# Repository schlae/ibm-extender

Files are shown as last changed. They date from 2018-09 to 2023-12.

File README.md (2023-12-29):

# IBM 5161 Expansion Chassis Cards

This project duplicates both the extender and receiver cards used in the IBM
5161 expansion chassis. This is a box that looks identical to an IBM PC, only
it has simple backplane instead of a motherboard. An extender card located in
a host PC/XT system connects to a receiver card located in the expansion
chassis using a large 62-pin D-sub cable.

Even if you don't own (all or part) of an IBM 5161, this project may still be
useful to you. It works perfectly with various passive ISA backplanes! There
is one slight catch--the 14.318MHz ISA bus clock signal is generated on the
IBM backplane but not typically on passive ISA backplanes. Not all cards need
this signal, however. Often you can check by tracing the edge connector contact
B30 on the back of an ISA card. It is second-furthest from the bracket. If the
contact is missing or not connected to a trace, the card should work.

Further information on the IBM 5161 is available from [minuszerodegrees.net](http://minuszerodegrees.net/5161/doco/5161_documentation.htm).

Someone else has reverse engineered and cloned the 5161 backplane. See [here](https://gitlab.com/trs-eric/5161-planar-backplane-board).

Incidentally, the 62-pin cable is available from Mouser Electronics,
923-PCL-10162-1E. Use the 1 meter cable; anything longer may cause signal
integrity issues.

The card bracket, Mouser Electronics 534-9200-5, has been reported to fit.
I have not personally tried it.

The IBM PC and XT BIOS run some tests on the card on boot. If you see an
"1801" code on boot, it may mean something as simple as an unconnected cable
or an unpowered expansion chassis. It'll pop up for any other error with the
card. For troubleshooting, you may have more luck writing test programs in
BASIC using the inp() and out() functions. Test registers are documented
in the [IBM technical reference manual](http://minuszerodegrees.net/oa/OA%20-%20IBM%20Expansion%20Unit%20(5161).pdf).

On to the cards themselves! These are both 4-layer boards. I got mine with
immersion gold edge fingers and a 30 degree edge bevel, but both these are
optional. The ideal is to use selective hard gold for the edge fingers,
but this tends to be quite expensive.

## Extender Card
Here is what the extender card looks like. Components shown may vary from the
official bill of materials.
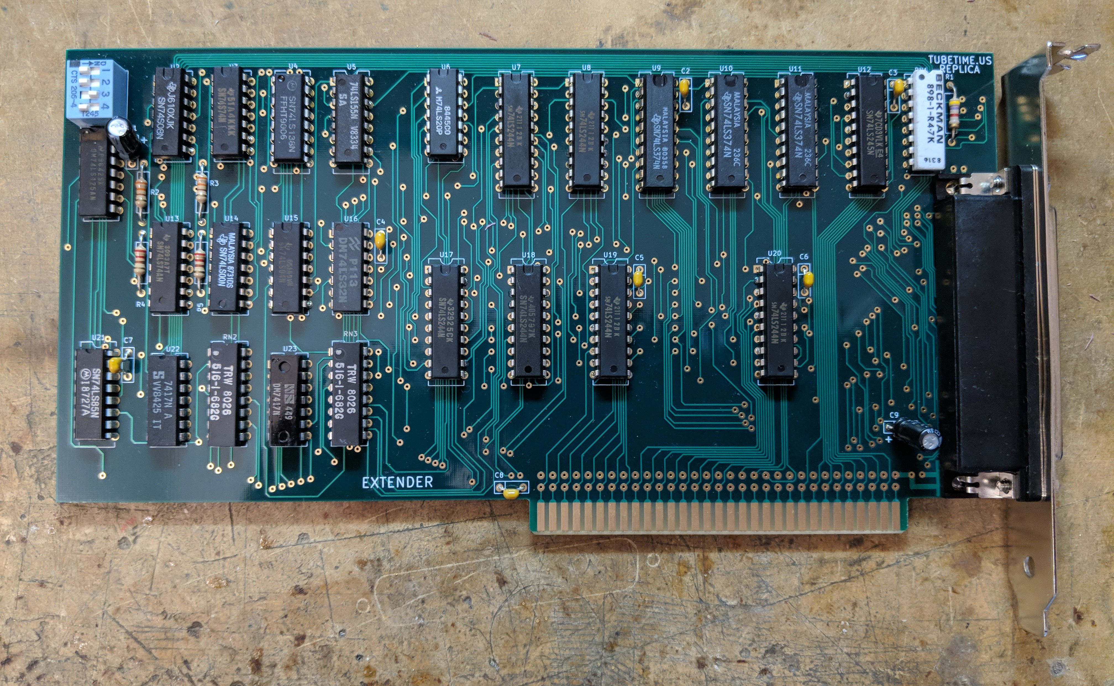
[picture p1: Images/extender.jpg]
Extender card photo


There is a switch bank in the upper left corner. This configures the wait-state
generator which is necessary if you need to access RAM or ROM on any other card
in the expansion chassis. Placing RAM expansion cards in the chassis is not
recommended since it slows everything down. The wait-state generator starts at
0xEFFFF and extends downwards to the configured address. ROM at 0xF0000-0xFFFFF
is reserved for system BIOS and never gets an additional wait state.

1=On, 0=Off/Open

| Switches  1234 | Address Range with Wait State |
|:---:|---|
| 1111 | 0x00000-0xEFFFF |
| 1110 | 0x10000-0xEFFFF |
| 1101 | 0x20000-0xEFFFF |
| 1100 | 0x30000-0xEFFFF |
| 1011 | 0x40000-0xEFFFF |
| 1010 | 0x50000-0xEFFFF |
| 1001 | 0x60000-0xEFFFF |
| 1000 | 0x70000-0xEFFFF |
| 0111 | 0x80000-0xEFFFF |
| 0110 | 0x90000-0xEFFFF |
| 0101 | 0xA0000-0xEFFFF |
| 0100 | 0xB0000-0xEFFFF |
| 0011 | 0xC0000-0xEFFFF |
| 0010 | 0xD0000-0xEFFFF |
| 0001 | 0xE0000-0xEFFFF |
| 0000 | Wait-state generator disabled |

Following are reference materials for your convenience.

[Schematic](https://github.com/schlae/ibm-extender/blob/master/Extender/IBMExtender.pdf)

[Bill of materials](https://github.com/schlae/ibm-extender/blob/master/Extender/IBMExtenderBOM.csv)

[Fab files](https://github.com/schlae/ibm-extender/raw/master/Extender/fab/IBMExtender.zip)

### Mistakes in the IBM Schematic
The IBM schematic has some errors:

1. Pin 2 of U1 was tied to EDACK1#. It should have been tied to ECLK to match the layout.
2. U8 pin 14 goes to RN2 pin 1 (pin number not shown on schematic).
3. Pin 2 of RN2 and pin 9 of RN3 were swapped on the schematic compared to the layout.
4. The board itself has a blue wire from pin 11 of U13 to what appears to be pin 4 of U2 (where the signal comes out to a via below the chip, not the actual pin). This wire has been incorporated in my design so you don't have to worry about it.

## Receiver Card
And here is what the receiver card looks like. Again, components shown may vary
from the official bill of materials.

There is one part on here, the delay line TD1, that may be more difficult to
find. It's a DS1005 or a 14T150 which is not something that Mouser stocks
anymore. You may be able to find one on auction sites, brokers, or you might
want to buy a more modern SMD delay line and wire up an adapter board. As long
as it provides a 150ns delay and supports 5V I/O, it should work.

Receiver card photo

[Schematic](https://github.com/schlae/ibm-extender/blob/master/Receiver/IBMReceiver.pdf)

[Bill of materials](https://github.com/schlae/ibm-extender/blob/master/Receiver/IBMReceiverBOM.csv)

[Fab files](https://github.com/schlae/ibm-extender/raw/master/Receiver/fab/IBMReceiver.zip)

### Mistakes in the IBM Schematic
Again, the IBM schematic has errors in it.

1. Pin 37 and 39 of J1 (D shell connector) are swapped. EDACK3#, EIOR#.
2. Pin 12 of U11 was tied to pin 3 of U2. It should be tied to pin 2 of U2. Signal ENABLE# was tied to pin 2 of U2. It should be tied to pin 3 of U2.

# License

This work is licensed under a Creative Commons Attribution 4.0 International License. See [https://creativecommons.org/licenses/by/4.0/](https://creativecommons.org/licenses/by/4.0/).

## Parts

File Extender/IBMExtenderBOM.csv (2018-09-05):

Item | Qty | Reference(s) | Value | LibPart | Footprint | Mouser
1 | 2 | C1, C9 | 10uF | device:CP1_Small | Passive:C_Disc_D0.2in_W0.1in_P0.2in | 581-TAP106K016CRS
2 | 7 | C2, C3, C4, C5, C6, C7, C8 | 0.1uF | device:C_Small | Passive:C_Disc_D0.2in_W0.1in_P0.2in | 594-K104K15X7RF53H5
3 | 1 | J1 | DB62 | connectors:DB62 | Conn:DB62 | 636-181-062-213R561
5 | 1 | R1 | 4.7K | device:R | Passive:R_Axial_L0.26in_D0.92in_P0.5in_Horizontal | 603-CFR-25JR-524K7
6 | 2 | R2, R3 | 330 | device:R | Passive:R_Axial_L0.26in_D0.92in_P0.5in_Horizontal | 603-CFR-25JR-52330R
7 | 2 | R4, R5 | 220 | device:R | Passive:R_Axial_L0.26in_D0.92in_P0.5in_Horizontal | 603-CFR-25JR-52220R
8 | 1 | RN1 | 4.7K | discretes:RPAC15_BUSSED | Active:DIP254P762X635-16 | 652-4116R-2LF-4.7K
9 | 2 | RN2, RN3 | 8.2K | discretes:RPAC15_BUSSED_IND | Active:DIP254P762X635-16 | 652-4116R-2LF-10K
10 | 1 | SW1 | SW_DIP_x04 | switches:SW_DIP_x04 | Buttons_Switches_THT:SW_DIP_x4_W7.62mm_Slide | 774-2064
11 | 1 | U1 | 74LS125 | 74xx:74LS125 | Active:DIP254P762X635-14 | 595-SN74LS125AN
12 | 1 | U2 | 74S08 | 74xx:74LS08 | Active:DIP254P762X635-14 | 595-SN74S08N
13 | 1 | U3 | 74S74 | 74xx:74LS74 | Active:DIP254P762X635-14 | 595-SN74S74N
14 | 1 | U4 | 74LS138 | 74xx:74LS138 | Active:DIP254P762X635-16 | 595-SN74LS138N
15 | 1 | U5 | 74LS155 | 74xx:74LS155 | Active:DIP254P762X635-16 | 595-SN74LS155AN
16 | 1 | U6 | 74LS20 | 74xx:74LS20 | Active:DIP254P762X635-14 | 595-SN74LS20N
17 | 6 | U7, U8, U17, U18, U19, U20 | 74LS244 | 74xx:74LS244 | Active:DIP254P762X635-20 | 595-SN74LS244N
18 | 3 | U9, U10, U11 | 74LS374 | 74xx:74LS374 | Active:DIP254P762X635-20 | 595-SN74LS374N
19 | 1 | U12 | 74LS245 | 74xx:74LS245 | Active:DIP254P762X635-20 | 595-SN74LS245N
20 | 1 | U13 | 74LS74 | 74xx:74LS74 | Active:DIP254P762X635-14 | 595-SN74LS74AN
21 | 1 | U14 | 74LS00 | 74xx:74LS00 | Active:DIP254P762X635-14 | 595-SN74LS00N
22 | 1 | U15 | 74LS04 | 74xx:74LS04 | Active:DIP254P762X635-14 | 595-SN74LS04N
23 | 1 | U16 | 74LS32 | 74xx:74LS32 | Active:DIP254P762X635-14 | 595-SN74LS32N
24 | 1 | U21 | 74S85 | 74xx:74LS85 | Active:DIP254P762X635-16 | 595-SN74LS85N
25 | 2 | U22, U23 | SN7417 | logic:SN7417 | Active:DIP254P762X635-14 | 595-SN7417N

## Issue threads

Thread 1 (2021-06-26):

This bracket fits

Exceter007, 2021-06-26:
I recently built an extender card based on your project and it works perfectly! Thank you! While I was ordering parts, I noticed that the BOM for the Extender didn't have a Mouser part number for a bracket. I was able to find one which fits and I thought you might like to add it to the BOM. The Mouser part number is 534-9200-5. Here's a picture of it fitted to my card: https://ibb.co/GHkPnwG

schlae, 2021-06-26:
Thanks for the suggestion, I've added it to the readme.

Closed 2021-06-26.

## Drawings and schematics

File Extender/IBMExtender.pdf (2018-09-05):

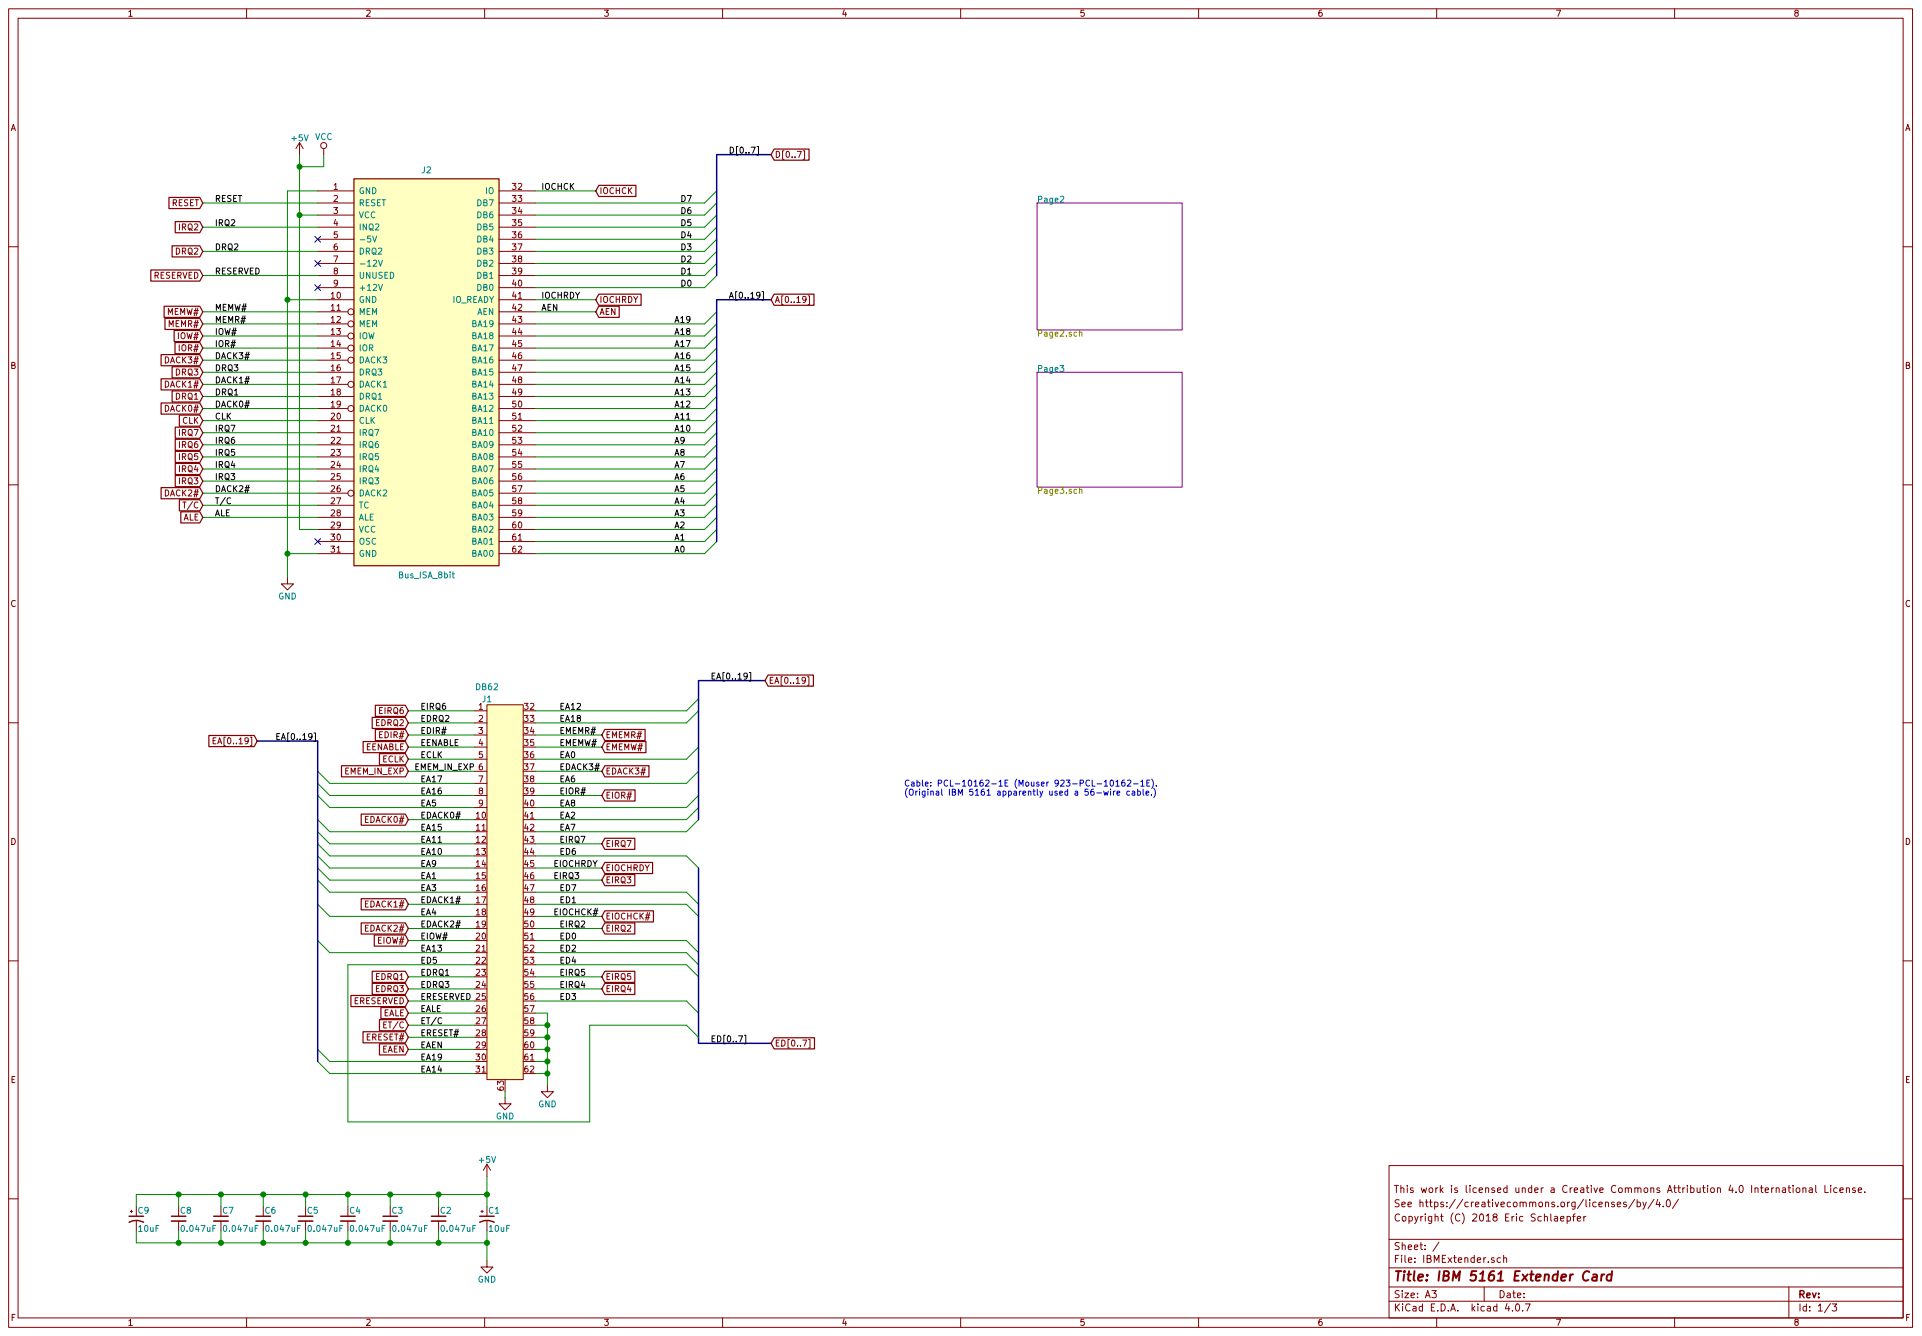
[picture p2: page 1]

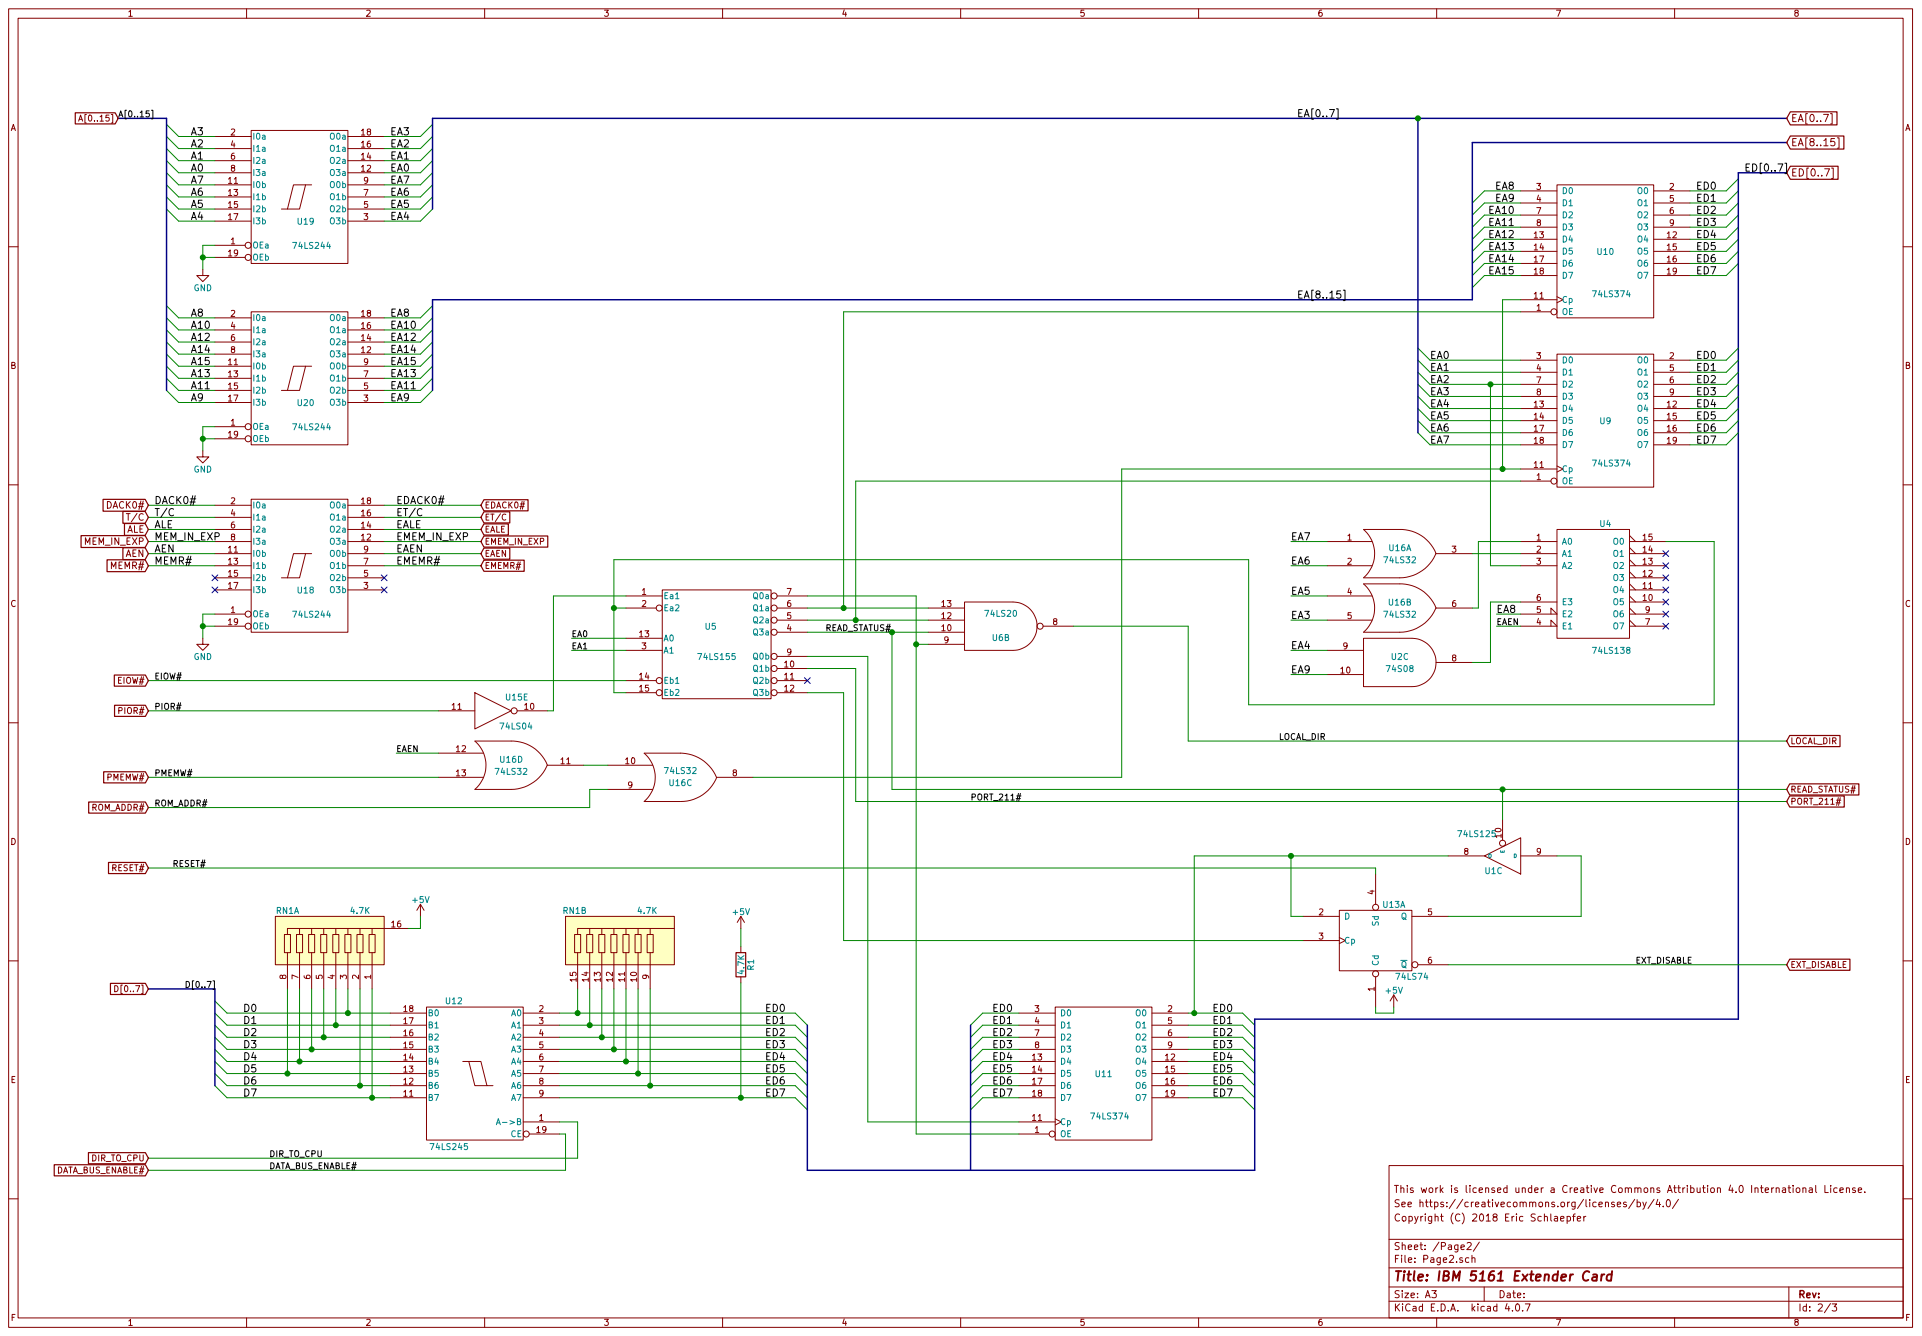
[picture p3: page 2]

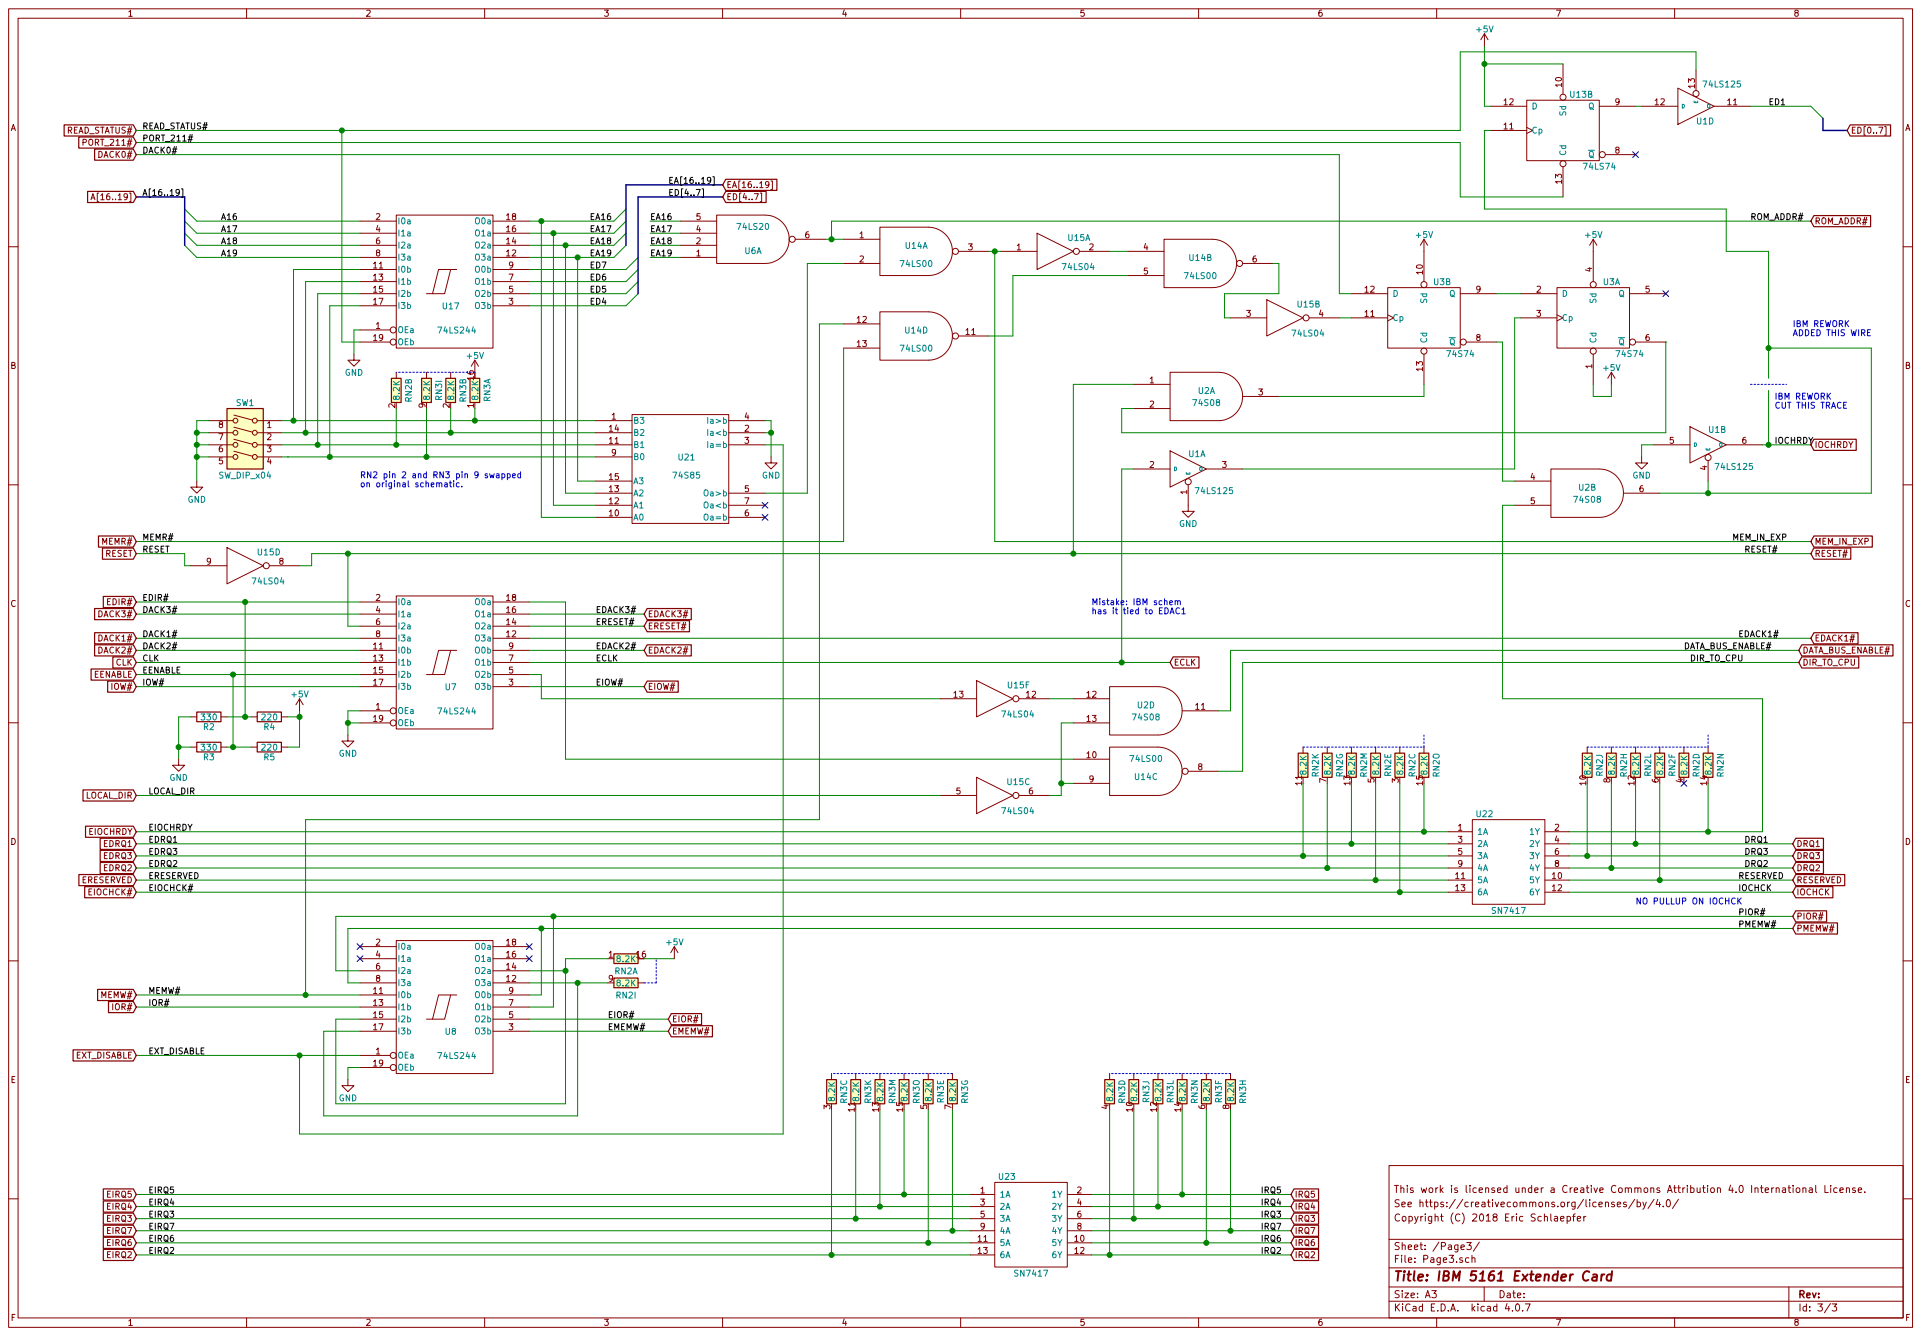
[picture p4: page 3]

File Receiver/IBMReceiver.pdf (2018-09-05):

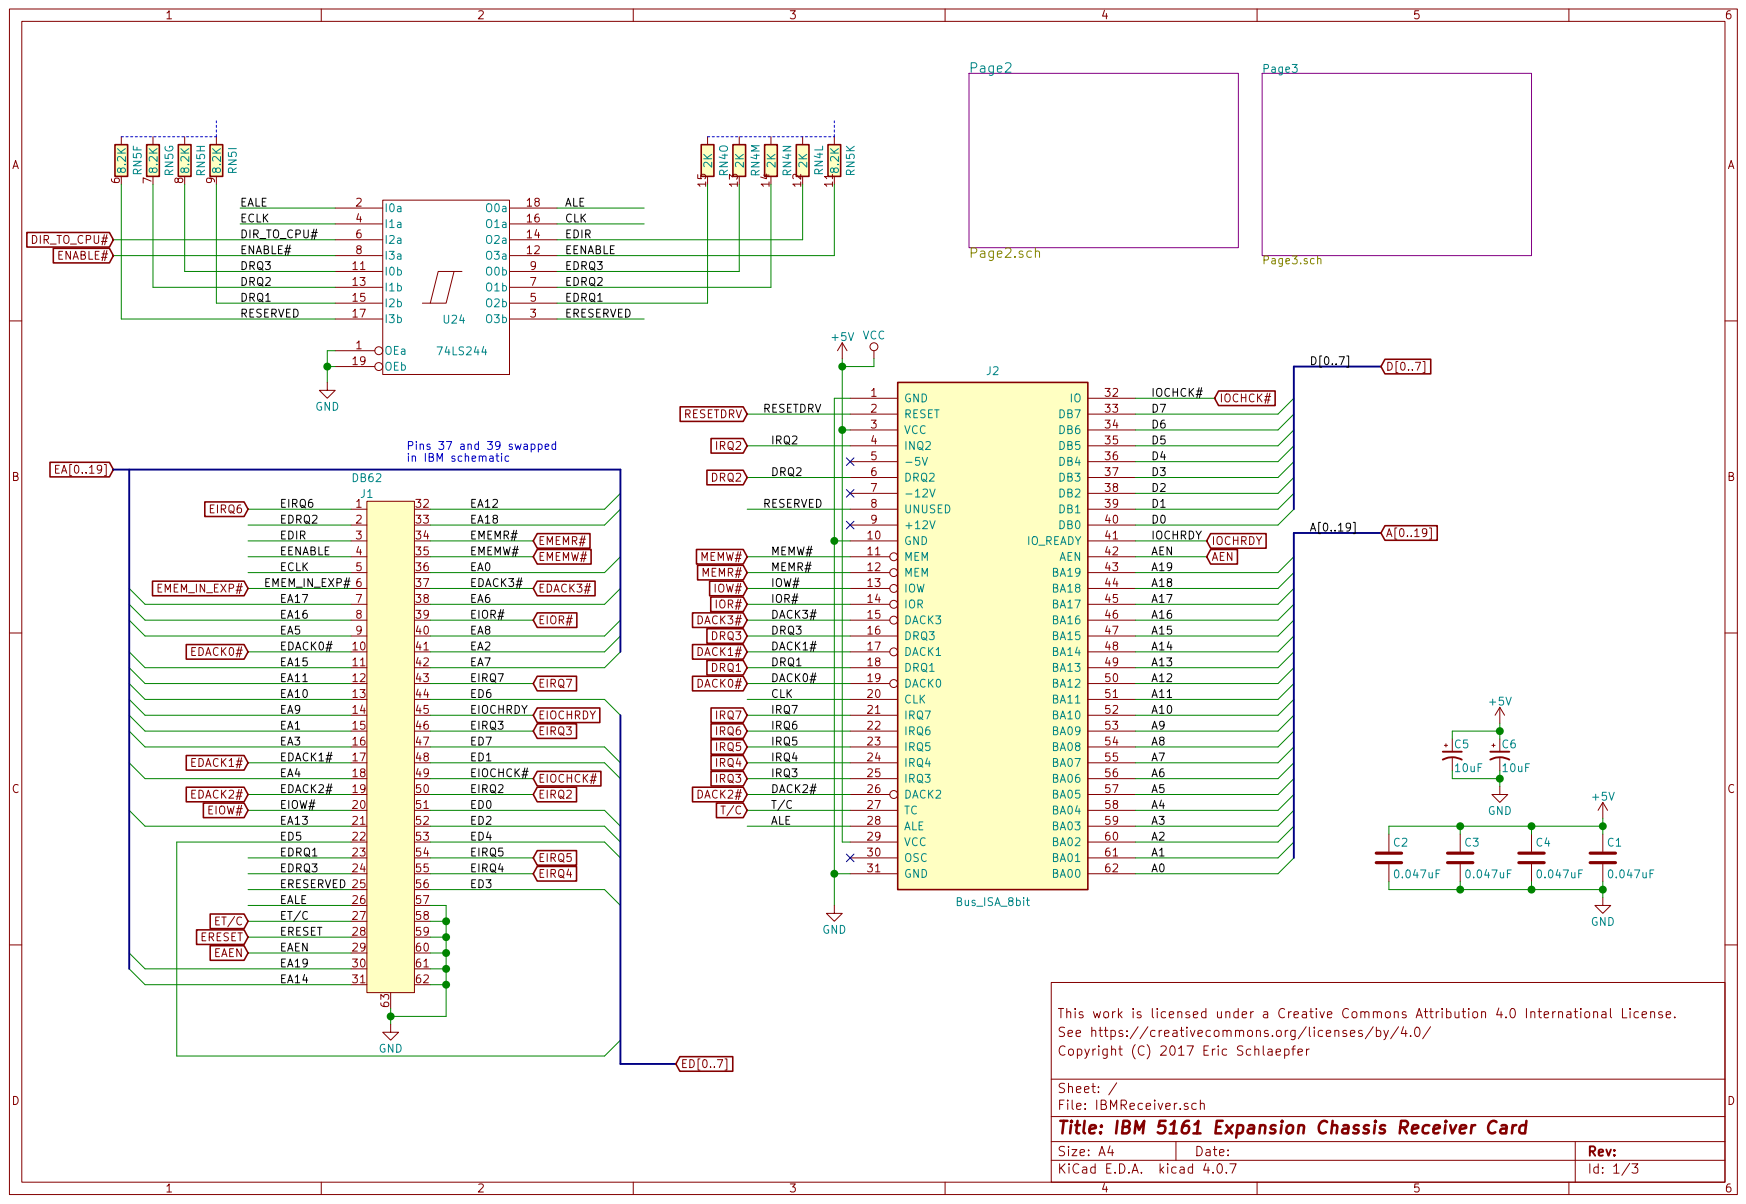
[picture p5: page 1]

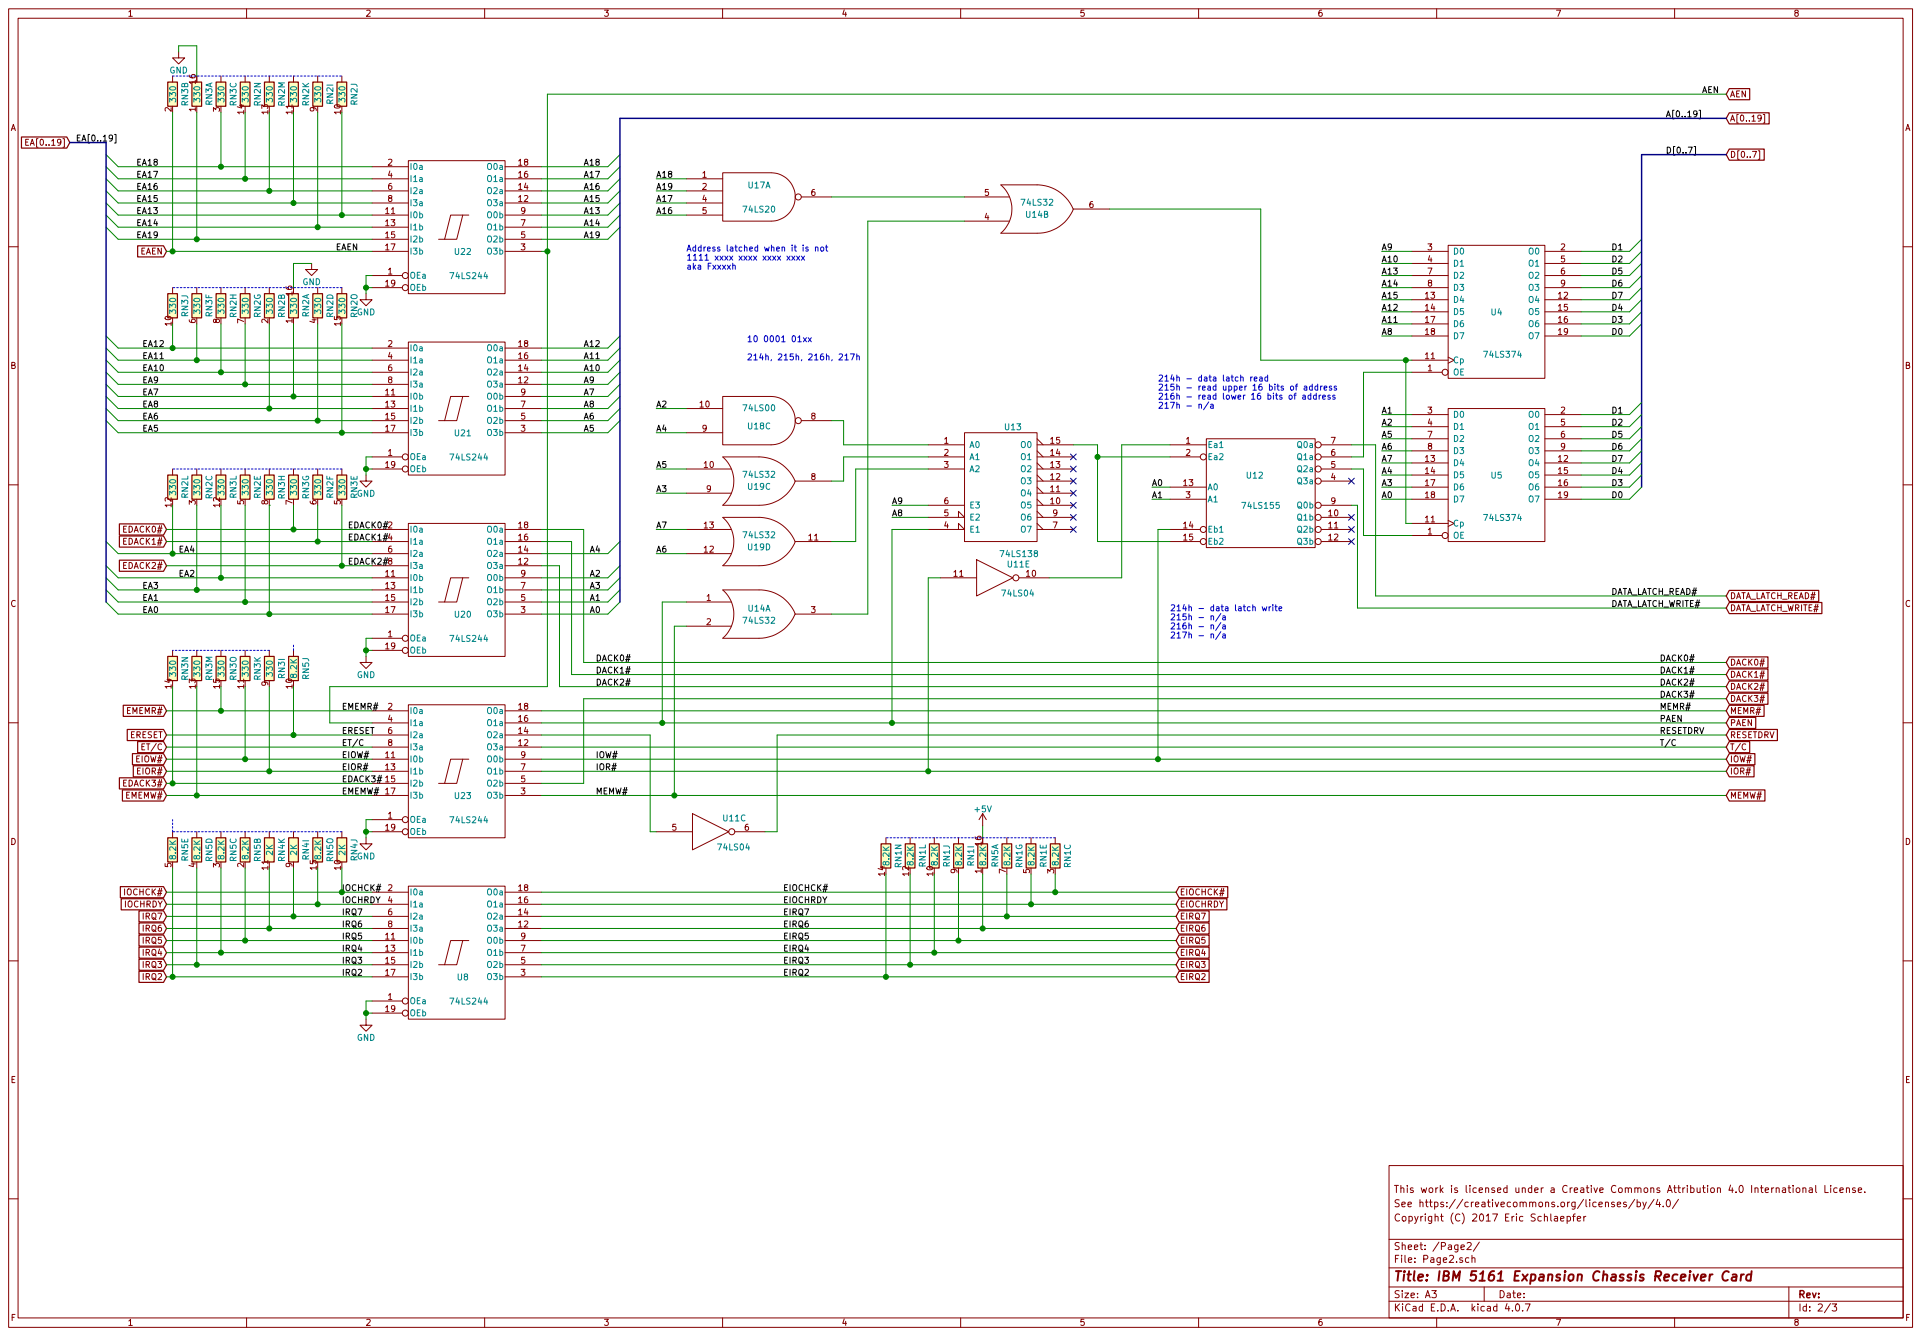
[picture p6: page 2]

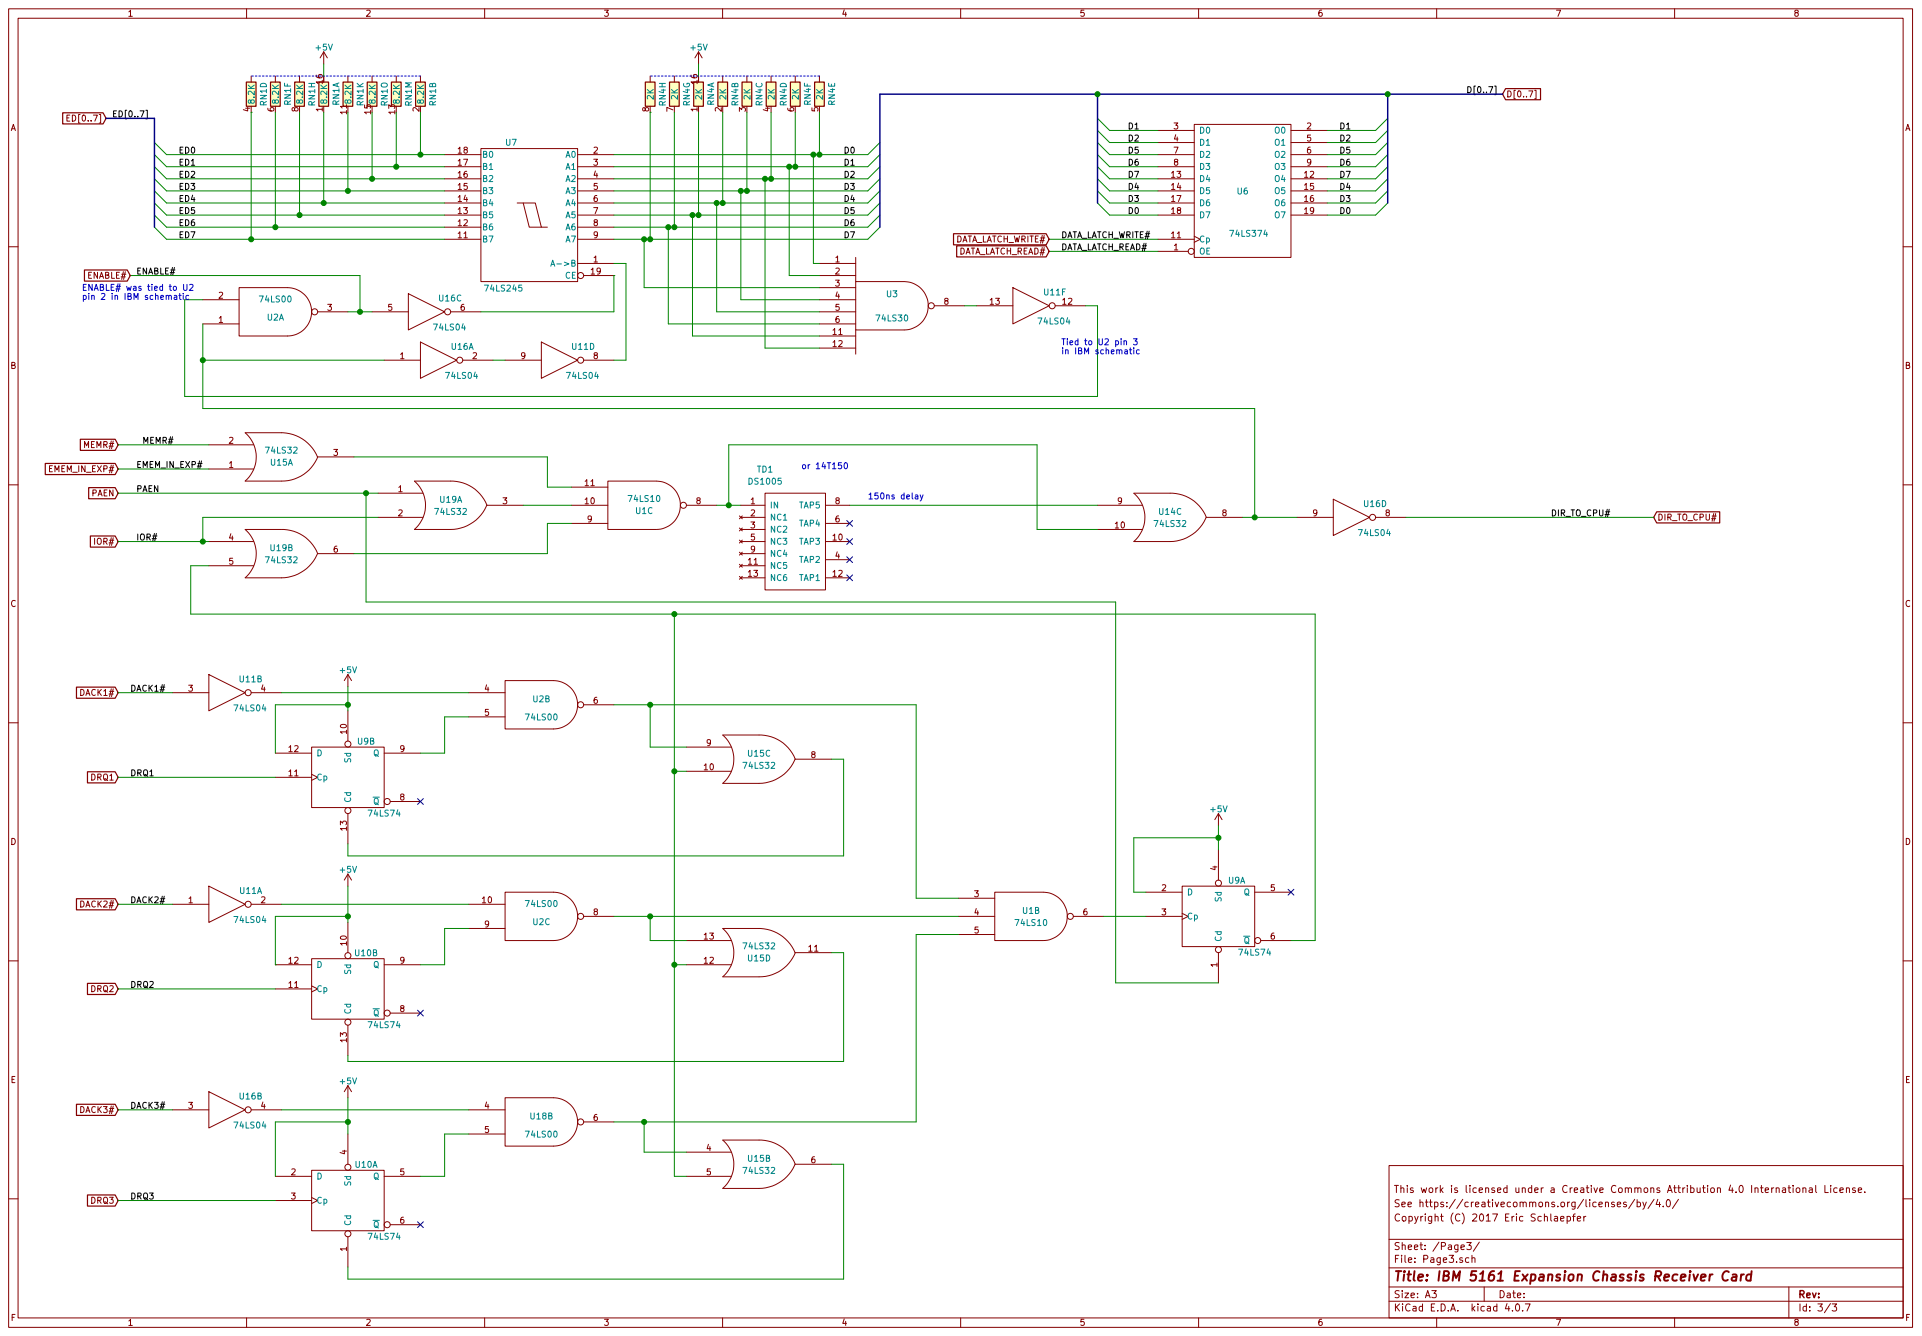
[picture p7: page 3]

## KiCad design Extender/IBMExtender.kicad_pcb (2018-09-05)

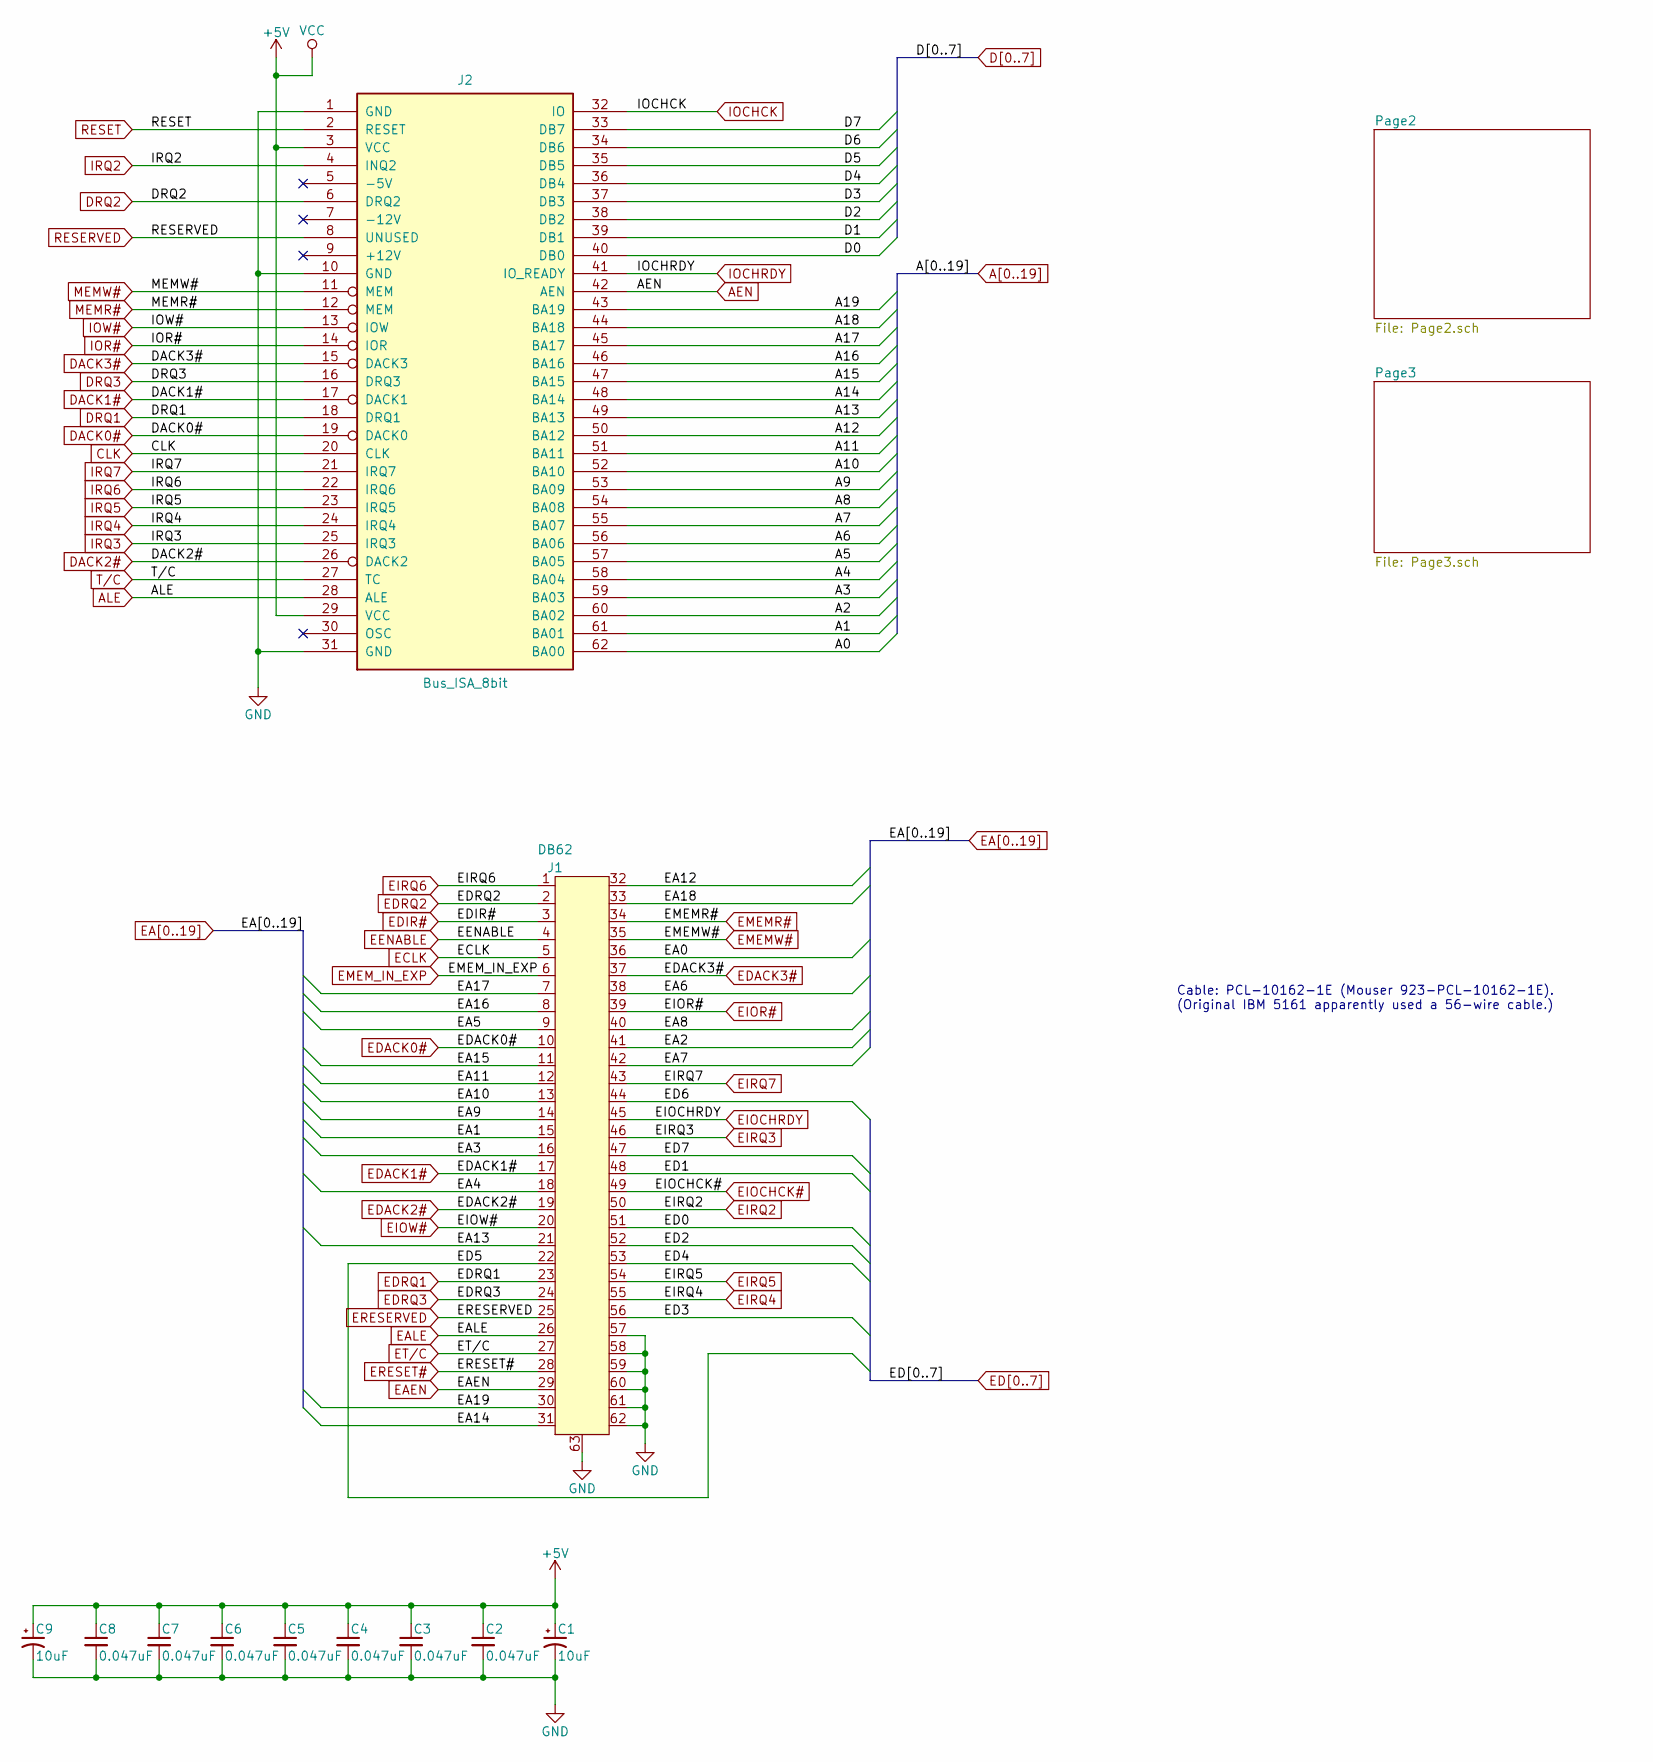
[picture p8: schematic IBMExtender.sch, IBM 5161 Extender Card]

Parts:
C1, C9: 10uF; C_Disc_D0.2in_W0.1in_P0.2in
C2, C3, C4, C5, C6, C7, C8: 0.047uF; C_Disc_D0.2in_W0.1in_P0.2in
J1: DB62; Mouser 636-181-062-213R561
J2: Bus_ISA_8bit; BUS_PC

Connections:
+5V: C1.1, C2.1, C3.1, C4.1, C5.1, C6.1, C7.1, C8.1, C9.1, J2.3 (VCC), J2.29 (VCC); also elsewhere on the board
A0: J2.62 (BA00); also elsewhere on the board
A1: J2.61 (BA01); also elsewhere on the board
A2: J2.60 (BA02); also elsewhere on the board
A3: J2.59 (BA03); also elsewhere on the board
A4: J2.58 (BA04); also elsewhere on the board
A5: J2.57 (BA05); also elsewhere on the board
A6: J2.56 (BA06); also elsewhere on the board
A7: J2.55 (BA07); also elsewhere on the board
A8: J2.54 (BA08); also elsewhere on the board
A9: J2.53 (BA09); also elsewhere on the board
A10: J2.52 (BA10); also elsewhere on the board
A11: J2.51 (BA11); also elsewhere on the board
A12: J2.50 (BA12); also elsewhere on the board
A13: J2.49 (BA13); also elsewhere on the board
A14: J2.48 (BA14); also elsewhere on the board
A15: J2.47 (BA15); also elsewhere on the board
A16: J2.46 (BA16); also elsewhere on the board
A17: J2.45 (BA17); also elsewhere on the board
A18: J2.44 (BA18); also elsewhere on the board
A19: J2.43 (BA19); also elsewhere on the board
AEN: J2.42 (AEN); also elsewhere on the board
ALE: J2.28 (ALE); also elsewhere on the board
CLK: J2.20 (CLK); also elsewhere on the board
D0: J2.40 (DB0); also elsewhere on the board
D1: J2.39 (DB1); also elsewhere on the board
D2: J2.38 (DB2); also elsewhere on the board
D3: J2.37 (DB3); also elsewhere on the board
D4: J2.36 (DB4); also elsewhere on the board
D5: J2.35 (DB5); also elsewhere on the board
D6: J2.34 (DB6); also elsewhere on the board
D7: J2.33 (DB7); also elsewhere on the board
DACK0#: J2.19 (DACK0); also elsewhere on the board
DACK1#: J2.17 (DACK1); also elsewhere on the board
DACK2#: J2.26 (DACK2); also elsewhere on the board
DACK3#: J2.15 (DACK3); also elsewhere on the board
DRQ1: J2.18 (DRQ1); also elsewhere on the board
DRQ2: J2.6 (DRQ2); also elsewhere on the board
DRQ3: J2.16 (DRQ3); also elsewhere on the board
EA0: J1.36; also elsewhere on the board
EA1: J1.15; also elsewhere on the board
EA2: J1.41; also elsewhere on the board
EA3: J1.16; also elsewhere on the board
EA4: J1.18; also elsewhere on the board
EA5: J1.9; also elsewhere on the board
EA6: J1.38; also elsewhere on the board
EA7: J1.42; also elsewhere on the board
EA8: J1.40; also elsewhere on the board
EA9: J1.14; also elsewhere on the board
EA10: J1.13; also elsewhere on the board
EA11: J1.12; also elsewhere on the board
EA12: J1.32; also elsewhere on the board
EA13: J1.21; also elsewhere on the board
EA14: J1.31; also elsewhere on the board
EA15: J1.11; also elsewhere on the board
EA16: J1.8; also elsewhere on the board
EA17: J1.7; also elsewhere on the board
EA18: J1.33; also elsewhere on the board
EA19: J1.30; also elsewhere on the board
EAEN: J1.29; also elsewhere on the board
EALE: J1.26; also elsewhere on the board
ECLK: J1.5; also elsewhere on the board
ED0: J1.51; also elsewhere on the board
ED1: J1.48; also elsewhere on the board
ED2: J1.52; also elsewhere on the board
ED3: J1.56; also elsewhere on the board
ED4: J1.53; also elsewhere on the board
ED5: J1.22; also elsewhere on the board
ED6: J1.44; also elsewhere on the board
ED7: J1.47; also elsewhere on the board
EDACK0#: J1.10; also elsewhere on the board
EDACK1#: J1.17; also elsewhere on the board
EDACK2#: J1.19; also elsewhere on the board
EDACK3#: J1.37; also elsewhere on the board
EDIR#: J1.3; also elsewhere on the board
EDRQ1: J1.23; also elsewhere on the board
EDRQ2: J1.2; also elsewhere on the board
EDRQ3: J1.24; also elsewhere on the board
EENABLE: J1.4; also elsewhere on the board
EIOCHCK#: J1.49; also elsewhere on the board
EIOCHRDY: J1.45; also elsewhere on the board
EIOR#: J1.39; also elsewhere on the board
EIOW#: J1.20; also elsewhere on the board
EIRQ2: J1.50; also elsewhere on the board
EIRQ3: J1.46; also elsewhere on the board
EIRQ4: J1.55; also elsewhere on the board
EIRQ5: J1.54; also elsewhere on the board
EIRQ6: J1.1; also elsewhere on the board
EIRQ7: J1.43; also elsewhere on the board
EMEMR#: J1.34; also elsewhere on the board
EMEMW#: J1.35; also elsewhere on the board
EMEM_IN_EXP: J1.6; also elsewhere on the board
ERESERVED: J1.25; also elsewhere on the board
ERESET#: J1.28; also elsewhere on the board
ET/C: J1.27; also elsewhere on the board
GND: C1.2, C2.2, C3.2, C4.2, C5.2, C6.2, C7.2, C8.2, C9.2, J1.57, J1.58, J1.59, J1.60, J1.61, J1.62, J1.63, J2.1 (GND), J2.10 (GND), J2.31 (GND); also elsewhere on the board
IOCHCK: J2.32 (IO); also elsewhere on the board
IOCHRDY: J2.41 (IO_READY); also elsewhere on the board
IOR#: J2.14 (IOR); also elsewhere on the board
IOW#: J2.13 (IOW); also elsewhere on the board
IRQ2: J2.4 (INQ2); also elsewhere on the board
IRQ3: J2.25 (IRQ3); also elsewhere on the board
IRQ4: J2.24 (IRQ4); also elsewhere on the board
IRQ5: J2.23 (IRQ5); also elsewhere on the board
IRQ6: J2.22 (IRQ6); also elsewhere on the board
IRQ7: J2.21 (IRQ7); also elsewhere on the board
MEMR#: J2.12 (MEM); also elsewhere on the board
MEMW#: J2.11 (MEM); also elsewhere on the board
RESERVED: J2.8 (UNUSED); also elsewhere on the board
RESET: J2.2 (RESET); also elsewhere on the board
T/C: J2.27 (TC); also elsewhere on the board

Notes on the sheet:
Cable: PCL-10162-1E (Mouser 923-PCL-10162-1E). (Original IBM 5161 apparently used a 56-wire cable.)

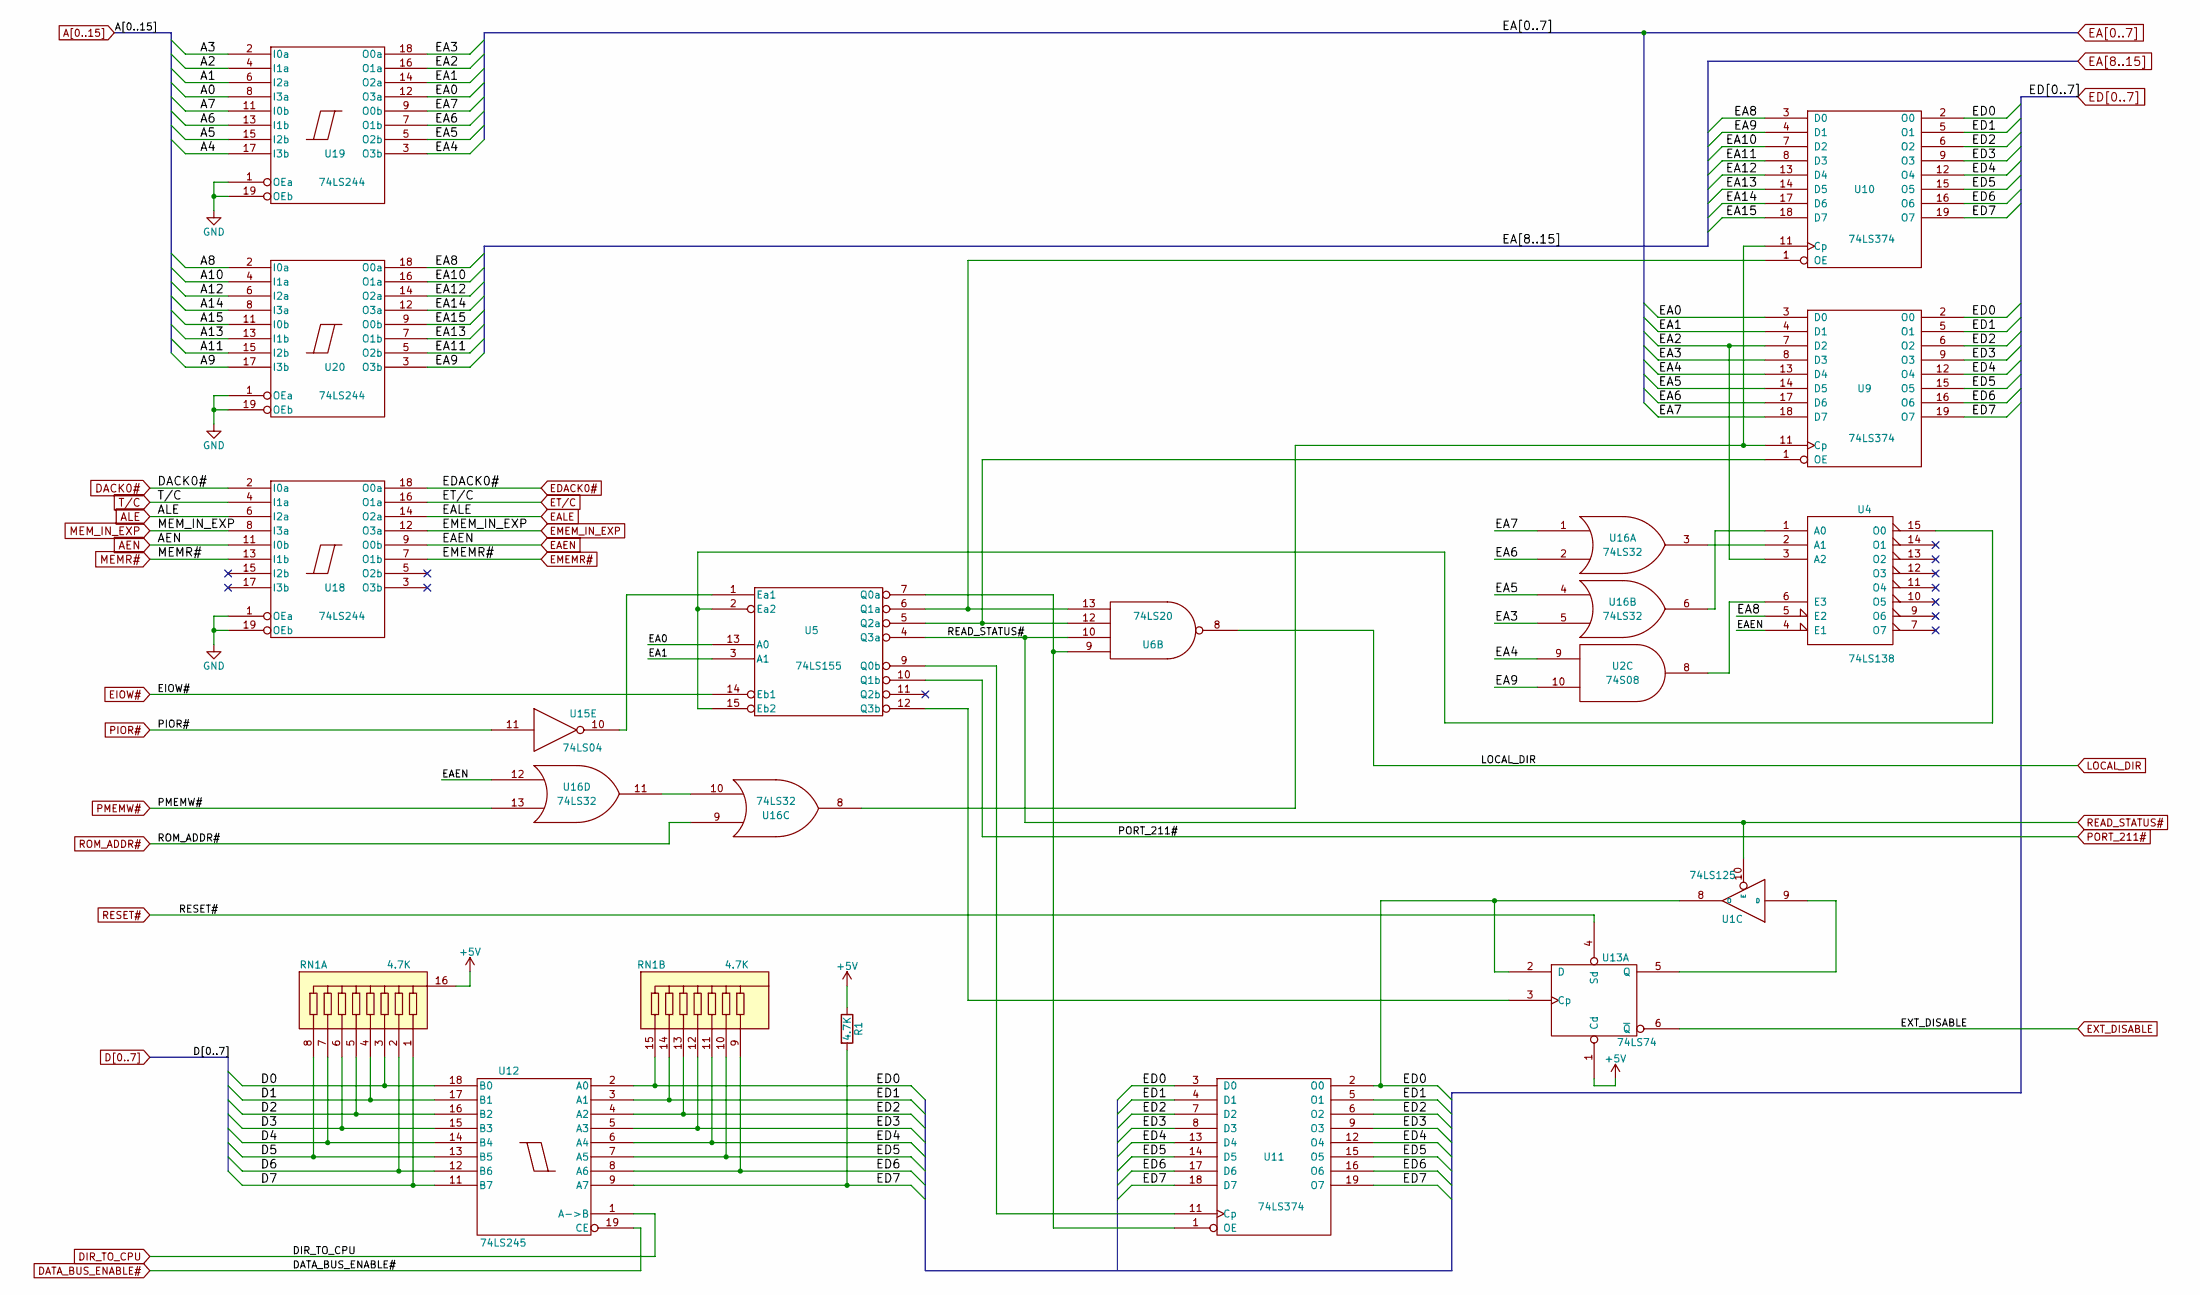
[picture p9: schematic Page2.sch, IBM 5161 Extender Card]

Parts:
R1: 4.7K; R_Axial_L0.26in_D0.92in_P0.5in_Horizontal
RN1: 4.7K; DIP254P762X635-16; Mouser 652-4116R-2LF-4.7K
U1: 74LS125; DIP254P762X635-14
U2: 74S08; DIP254P762X635-14
U4: 74LS138; DIP254P762X635-16
U5: 74LS155; DIP254P762X635-16
U6: 74LS20; DIP254P762X635-14
U9, U10, U11: 74LS374; DIP254P762X635-20
U12: 74LS245; DIP254P762X635-20
U13: 74LS74; DIP254P762X635-14
U15: 74LS04; DIP254P762X635-14
U16: 74LS32; DIP254P762X635-14
U18, U19, U20: 74LS244; DIP254P762X635-20

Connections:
+5V: R1.1, RN1.16, U1.14 (VCC), U2.14 (VCC), U4.16 (VCC), U5.16 (VCC), U6.14 (VCC), U9.20 (VCC), U10.20 (VCC), U11.20 (VCC), U12.20 (VCC), U13.1 (Cd), U13.14 (VCC), U15.14 (VCC), U16.14 (VCC), U18.20 (VCC), U19.20 (VCC), U20.20 (VCC); also elsewhere on the board
A0: U19.8 (I3a); also elsewhere on the board
A1: U19.6 (I2a); also elsewhere on the board
A2: U19.4 (I1a); also elsewhere on the board
A3: U19.2 (I0a); also elsewhere on the board
A4: U19.17 (I3b); also elsewhere on the board
A5: U19.15 (I2b); also elsewhere on the board
A6: U19.13 (I1b); also elsewhere on the board
A7: U19.11 (I0b); also elsewhere on the board
A8: U20.2 (I0a); also elsewhere on the board
A9: U20.17 (I3b); also elsewhere on the board
A10: U20.4 (I1a); also elsewhere on the board
A11: U20.15 (I2b); also elsewhere on the board
A12: U20.6 (I2a); also elsewhere on the board
A13: U20.13 (I1b); also elsewhere on the board
A14: U20.8 (I3a); also elsewhere on the board
A15: U20.11 (I0b); also elsewhere on the board
AEN: U18.11 (I0b); also elsewhere on the board
ALE: U18.6 (I2a); also elsewhere on the board
D0: RN1.3, U12.18 (B0); also elsewhere on the board
D1: RN1.4, U12.17 (B1); also elsewhere on the board
D2: RN1.5, U12.16 (B2); also elsewhere on the board
D3: RN1.6, U12.15 (B3); also elsewhere on the board
D4: RN1.7, U12.14 (B4); also elsewhere on the board
D5: RN1.8, U12.13 (B5); also elsewhere on the board
D6: RN1.2, U12.12 (B6); also elsewhere on the board
D7: RN1.1, U12.11 (B7); also elsewhere on the board
DACK0#: U18.2 (I0a); also elsewhere on the board
DATA_BUS_ENABLE#: U12.19 (CE); also elsewhere on the board
DIR_TO_CPU: U12.1 (A->B); also elsewhere on the board
EA0: U5.13 (A0), U9.3 (D0), U19.12 (O3a); also elsewhere on the board
EA1: U5.3 (A1), U9.4 (D1), U19.14 (O2a); also elsewhere on the board
EA2: U4.3 (A2), U9.7 (D2), U19.16 (O1a); also elsewhere on the board
EA3: U9.8 (D3), U16.5, U19.18 (O0a); also elsewhere on the board
EA4: U2.9, U9.13 (D4), U19.3 (O3b); also elsewhere on the board
EA5: U9.14 (D5), U16.4, U19.5 (O2b); also elsewhere on the board
EA6: U9.17 (D6), U16.2, U19.7 (O1b); also elsewhere on the board
EA7: U9.18 (D7), U16.1, U19.9 (O0b); also elsewhere on the board
EA8: U4.5 (E2), U10.3 (D0), U20.18 (O0a); also elsewhere on the board
EA9: U2.10, U10.4 (D1), U20.3 (O3b); also elsewhere on the board
EA10: U10.7 (D2), U20.16 (O1a); also elsewhere on the board
EA11: U10.8 (D3), U20.5 (O2b); also elsewhere on the board
EA12: U10.13 (D4), U20.14 (O2a); also elsewhere on the board
EA13: U10.14 (D5), U20.7 (O1b); also elsewhere on the board
EA14: U10.17 (D6), U20.12 (O3a); also elsewhere on the board
EA15: U10.18 (D7), U20.9 (O0b); also elsewhere on the board
EAEN: U4.4 (E1), U16.12, U18.9 (O0b); also elsewhere on the board
EALE: U18.14 (O2a); also elsewhere on the board
ED0: RN1.15, U1.8 (O), U9.2 (O0), U10.2 (O0), U11.2 (O0), U11.3 (D0), U12.2 (A0), U13.2 (D); also elsewhere on the board
ED1: RN1.14, U9.5 (O1), U10.5 (O1), U11.4 (D1), U11.5 (O1), U12.3 (A1); also elsewhere on the board
ED2: RN1.13, U9.6 (O2), U10.6 (O2), U11.6 (O2), U11.7 (D2), U12.4 (A2); also elsewhere on the board
ED3: RN1.12, U9.9 (O3), U10.9 (O3), U11.8 (D3), U11.9 (O3), U12.5 (A3); also elsewhere on the board
ED4: RN1.11, U9.12 (O4), U10.12 (O4), U11.12 (O4), U11.13 (D4), U12.6 (A4); also elsewhere on the board
ED5: RN1.10, U9.15 (O5), U10.15 (O5), U11.14 (D5), U11.15 (O5), U12.7 (A5); also elsewhere on the board
ED6: RN1.9, U9.16 (O6), U10.16 (O6), U11.16 (O6), U11.17 (D6), U12.8 (A6); also elsewhere on the board
ED7: R1.2, U9.19 (O7), U10.19 (O7), U11.18 (D7), U11.19 (O7), U12.9 (A7); also elsewhere on the board
EDACK0#: U18.18 (O0a); also elsewhere on the board
EIOW#: U5.14 (Eb1); also elsewhere on the board
EMEMR#: U18.7 (O1b); also elsewhere on the board
EMEM_IN_EXP: U18.12 (O3a); also elsewhere on the board
ET/C: U18.16 (O1a); also elsewhere on the board
EXT_DISABLE: U13.6 (~Q); also elsewhere on the board
GND: U1.7 (GND), U2.7 (GND), U4.8 (GND), U5.8 (GND), U6.7 (GND), U9.10 (GND), U10.10 (GND), U11.10 (GND), U12.10 (GND), U13.7 (GND), U15.7 (GND), U16.7 (GND), U18.1 (OEa), U18.10 (GND), U18.19 (OEb), U19.1 (OEa), U19.10 (GND), U19.19 (OEb), U20.1 (OEa), U20.10 (GND), U20.19 (OEb); also elsewhere on the board
LOCAL_DIR: U6.8; also elsewhere on the board
MEMR#: U18.13 (I1b); also elsewhere on the board
MEM_IN_EXP: U18.8 (I3a); also elsewhere on the board
unnamed: U1.9 (D), U13.5 (Q)
unnamed: U2.8, U4.6 (E3)
unnamed: U4.15 (O0), U5.2 (Ea2), U5.15 (Eb2)
unnamed: U5.5 (Q2a), U6.12, U9.1 (OE)
unnamed: U5.6 (Q1a), U6.13, U10.1 (OE)
unnamed: U9.11 (Cp), U10.11 (Cp), U16.8
unnamed: U5.7 (Q0a), U6.9, U11.1 (OE)
unnamed: U5.9 (Q0b), U11.11 (Cp)
unnamed: U5.12 (Q3b), U13.3 (Cp)
unnamed: U5.1 (Ea1), U15.10
unnamed: U4.2 (A1), U16.3
unnamed: U4.1 (A0), U16.6
unnamed: U16.10, U16.11
PIOR#: U15.11; also elsewhere on the board
PMEMW#: U16.13; also elsewhere on the board
PORT_211#: U5.10 (Q1b); also elsewhere on the board
READ_STATUS#: U1.10 (E), U5.4 (Q3a), U6.10; also elsewhere on the board
RESET#: U13.4 (Sd); also elsewhere on the board
ROM_ADDR#: U16.9; also elsewhere on the board
T/C: U18.4 (I1a); also elsewhere on the board

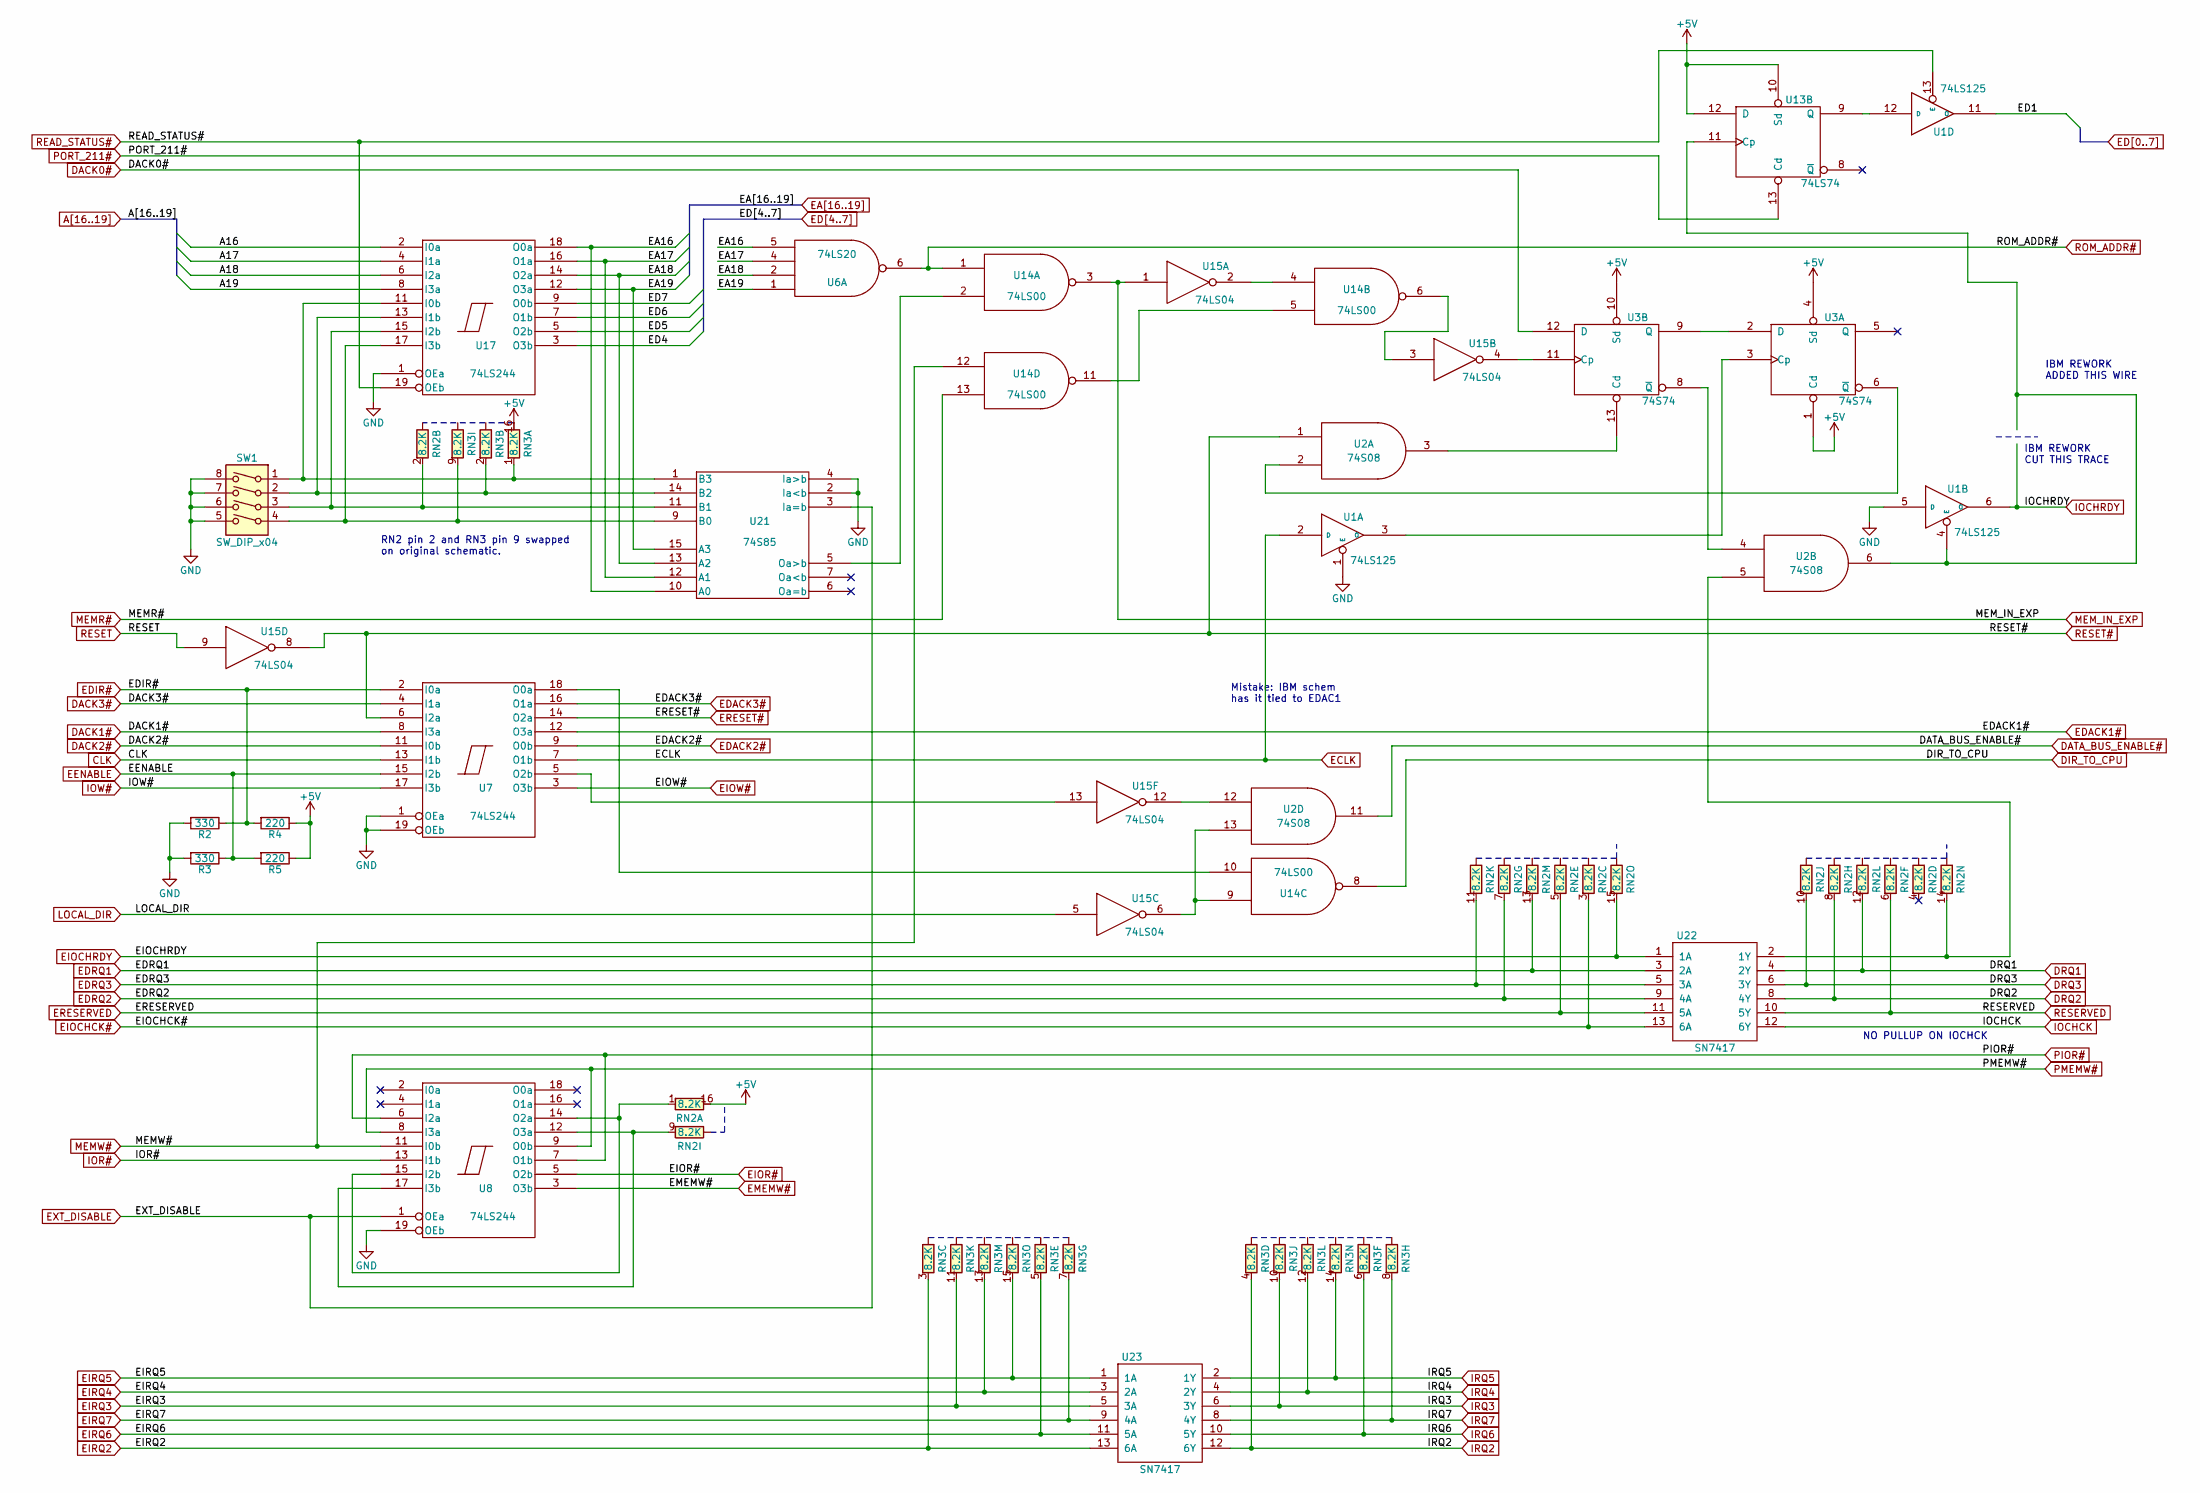
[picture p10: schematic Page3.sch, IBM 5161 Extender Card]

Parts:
R2, R3: 330; R_Axial_L0.26in_D0.92in_P0.5in_Horizontal
R4, R5: 220; R_Axial_L0.26in_D0.92in_P0.5in_Horizontal
RN2, RN3: 8.2K; DIP254P762X635-16; Mouser 4116R-2-104LF
SW1: SW_DIP_x04; SW_DIP_x4_W7.62mm_Slide
U1: 74LS125; DIP254P762X635-14
U2: 74S08; DIP254P762X635-14
U3: 74S74; DIP254P762X635-14
U6: 74LS20; DIP254P762X635-14
U7, U8, U17: 74LS244; DIP254P762X635-20
U13: 74LS74; DIP254P762X635-14
U14: 74LS00; DIP254P762X635-14
U15: 74LS04; DIP254P762X635-14
U21: 74S85; DIP254P762X635-16
U22, U23: SN7417; DIP254P762X635-14

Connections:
+5V: R4.1, R5.1, RN2.16, RN3.16, U1.14 (VCC), U2.14 (VCC), U3.1 (Cd), U3.4 (Sd), U3.10 (Sd), U3.14 (VCC), U6.14 (VCC), U7.20 (VCC), U8.20 (VCC), U13.10 (Sd), U13.12 (D), U13.14 (VCC), U14.14 (VCC), U15.14 (VCC), U17.20 (VCC), U21.16 (VCC), U22.14 (VCC), U23.14 (VCC); also elsewhere on the board
A16: U17.2 (I0a); also elsewhere on the board
A17: U17.4 (I1a); also elsewhere on the board
A18: U17.6 (I2a); also elsewhere on the board
A19: U17.8 (I3a); also elsewhere on the board
CLK: U7.13 (I1b); also elsewhere on the board
DACK0#: U3.12 (D); also elsewhere on the board
DACK1#: U7.8 (I3a); also elsewhere on the board
DACK2#: U7.11 (I0b); also elsewhere on the board
DACK3#: U7.4 (I1a); also elsewhere on the board
DATA_BUS_ENABLE#: U2.11; also elsewhere on the board
DIR_TO_CPU: U14.8; also elsewhere on the board
DRQ1: RN2.12, U22.4 (2Y); also elsewhere on the board
DRQ2: RN2.8, U22.8 (4Y); also elsewhere on the board
DRQ3: RN2.10, U22.6 (3Y); also elsewhere on the board
EA16: U6.5, U17.18 (O0a), U21.10 (A0); also elsewhere on the board
EA17: U6.4, U17.16 (O1a), U21.12 (A1); also elsewhere on the board
EA18: U6.2, U17.14 (O2a), U21.13 (A2); also elsewhere on the board
EA19: U6.1, U17.12 (O3a), U21.15 (A3); also elsewhere on the board
ECLK: U1.2 (D), U7.7 (O1b); also elsewhere on the board
ED1: U1.11 (O); also elsewhere on the board
ED4: U17.3 (O3b); also elsewhere on the board
ED5: U17.5 (O2b); also elsewhere on the board
ED6: U17.7 (O1b); also elsewhere on the board
ED7: U17.9 (O0b); also elsewhere on the board
EDACK1#: U7.12 (O3a); also elsewhere on the board
EDACK2#: U7.9 (O0b); also elsewhere on the board
EDACK3#: U7.16 (O1a); also elsewhere on the board
EDIR#: R2.1, R4.2, U7.2 (I0a); also elsewhere on the board
EDRQ1: RN2.13, U22.3 (2A); also elsewhere on the board
EDRQ2: RN2.7, U22.9 (4A); also elsewhere on the board
EDRQ3: RN2.11, U22.5 (3A); also elsewhere on the board
EENABLE: R3.1, R5.2, U7.15 (I2b); also elsewhere on the board
EIOCHCK#: RN2.3, U22.13 (6A); also elsewhere on the board
EIOCHRDY: RN2.15, U22.1 (1A); also elsewhere on the board
EIOR#: U8.5 (O2b); also elsewhere on the board
EIOW#: U7.3 (O3b); also elsewhere on the board
EIRQ2: RN3.3, U23.13 (6A); also elsewhere on the board
EIRQ3: RN3.11, U23.5 (3A); also elsewhere on the board
EIRQ4: RN3.13, U23.3 (2A); also elsewhere on the board
EIRQ5: RN3.15, U23.1 (1A); also elsewhere on the board
EIRQ6: RN3.5, U23.11 (5A); also elsewhere on the board
EIRQ7: RN3.7, U23.9 (4A); also elsewhere on the board
EMEMW#: U8.3 (O3b); also elsewhere on the board
ERESERVED: RN2.5, U22.11 (5A); also elsewhere on the board
ERESET#: U7.14 (O2a); also elsewhere on the board
EXT_DISABLE: U8.1 (OEa), U21.3 (Ia=b); also elsewhere on the board
GND: R2.2, R3.2, SW1.5, SW1.6, SW1.7, SW1.8, U1.1 (E), U1.5 (D), U1.7 (GND), U2.7 (GND), U3.7 (GND), U6.7 (GND), U7.1 (OEa), U7.10 (GND), U7.19 (OEb), U8.10 (GND), U8.19 (OEb), U13.7 (GND), U14.7 (GND), U15.7 (GND), U17.1 (OEa), U17.10 (GND), U21.2 (Ia<b), U21.4 (Ia>b), U21.8 (GND), U22.7 (GND), U23.7 (GND); also elsewhere on the board
IOCHCK: U22.12 (6Y); also elsewhere on the board
IOCHRDY: U1.6 (O); also elsewhere on the board
IOR#: U8.13 (I1b); also elsewhere on the board
IOW#: U7.17 (I3b); also elsewhere on the board
IRQ2: RN3.4, U23.12 (6Y); also elsewhere on the board
IRQ3: RN3.10, U23.6 (3Y); also elsewhere on the board
IRQ4: RN3.12, U23.4 (2Y); also elsewhere on the board
IRQ5: RN3.14, U23.2 (1Y); also elsewhere on the board
IRQ6: RN3.6, U23.10 (5Y); also elsewhere on the board
IRQ7: RN3.8, U23.8 (4Y); also elsewhere on the board
LOCAL_DIR: U15.5; also elsewhere on the board
MEMR#: U14.13; also elsewhere on the board
MEMW#: U8.11 (I0b), U14.12; also elsewhere on the board
MEM_IN_EXP: U14.3, U15.1; also elsewhere on the board
unnamed: RN2.1, U8.14 (O2a), U8.15 (I2b)
unnamed: RN2.2, SW1.3, U17.15 (I2b), U21.11 (B1)
unnamed: RN2.9, U8.12 (O3a), U8.17 (I3b)
unnamed: RN2.14, U2.5, U22.2 (1Y)
unnamed: RN3.1, SW1.1, U17.11 (I0b), U21.1 (B3)
unnamed: RN3.2, SW1.2, U17.13 (I1b), U21.14 (B2)
unnamed: RN3.9, SW1.4, U17.17 (I3b), U21.9 (B0)
unnamed: U1.3 (O), U3.3 (Cp)
unnamed: U1.4 (E), U2.6, U13.11 (Cp)
unnamed: U1.12 (D), U13.9 (Q)
unnamed: U2.2, U3.6 (~Q)
unnamed: U2.3, U3.13 (Cd)
unnamed: U2.4, U3.8 (~Q)
unnamed: U3.2 (D), U3.9 (Q)
unnamed: U14.2, U21.5 (Oa>b)
unnamed: U14.4, U15.2
unnamed: U14.6, U15.3
unnamed: U2.13, U14.9, U15.6
unnamed: U7.18 (O0a), U14.10
unnamed: U14.5, U14.11
unnamed: U3.11 (Cp), U15.4
unnamed: U2.12, U15.12
unnamed: U7.5 (O2b), U15.13
PIOR#: U8.6 (I2a), U8.7 (O1b); also elsewhere on the board
PMEMW#: U8.8 (I3a), U8.9 (O0b); also elsewhere on the board
PORT_211#: U13.13 (Cd); also elsewhere on the board
READ_STATUS#: U1.13 (E), U17.19 (OEb); also elsewhere on the board
RESERVED: RN2.6, U22.10 (5Y); also elsewhere on the board
RESET: U15.9; also elsewhere on the board
RESET#: U2.1, U7.6 (I2a), U15.8; also elsewhere on the board
ROM_ADDR#: U6.6, U14.1; also elsewhere on the board

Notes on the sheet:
NO PULLUP ON IOCHCK
Mistake: IBM schem has it tied to EDAC1
RN2 pin 2 and RN3 pin 9 swapped on original schematic.
IBM REWORK CUT THIS TRACE
IBM REWORK ADDED THIS WIRE

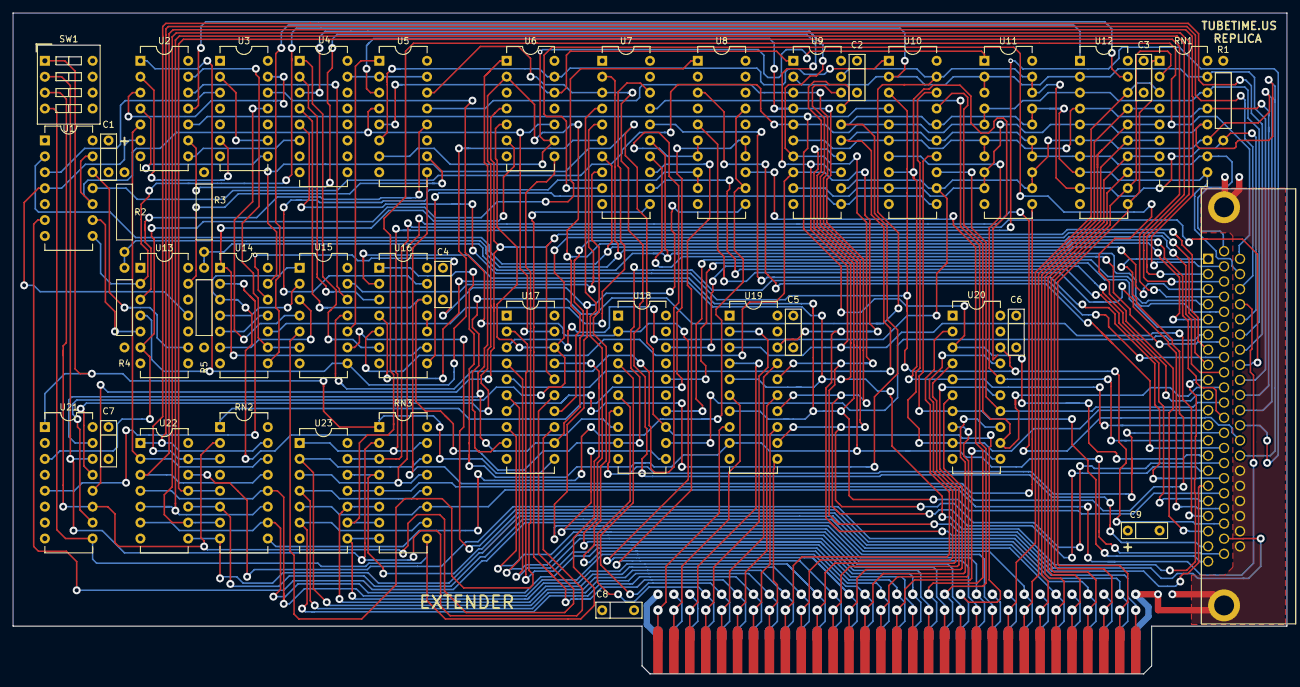
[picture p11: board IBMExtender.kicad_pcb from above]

Board: 4 copper layers, 203.2 x 105.4 mm, 43 parts (0 on the bottom side), 158 nets.

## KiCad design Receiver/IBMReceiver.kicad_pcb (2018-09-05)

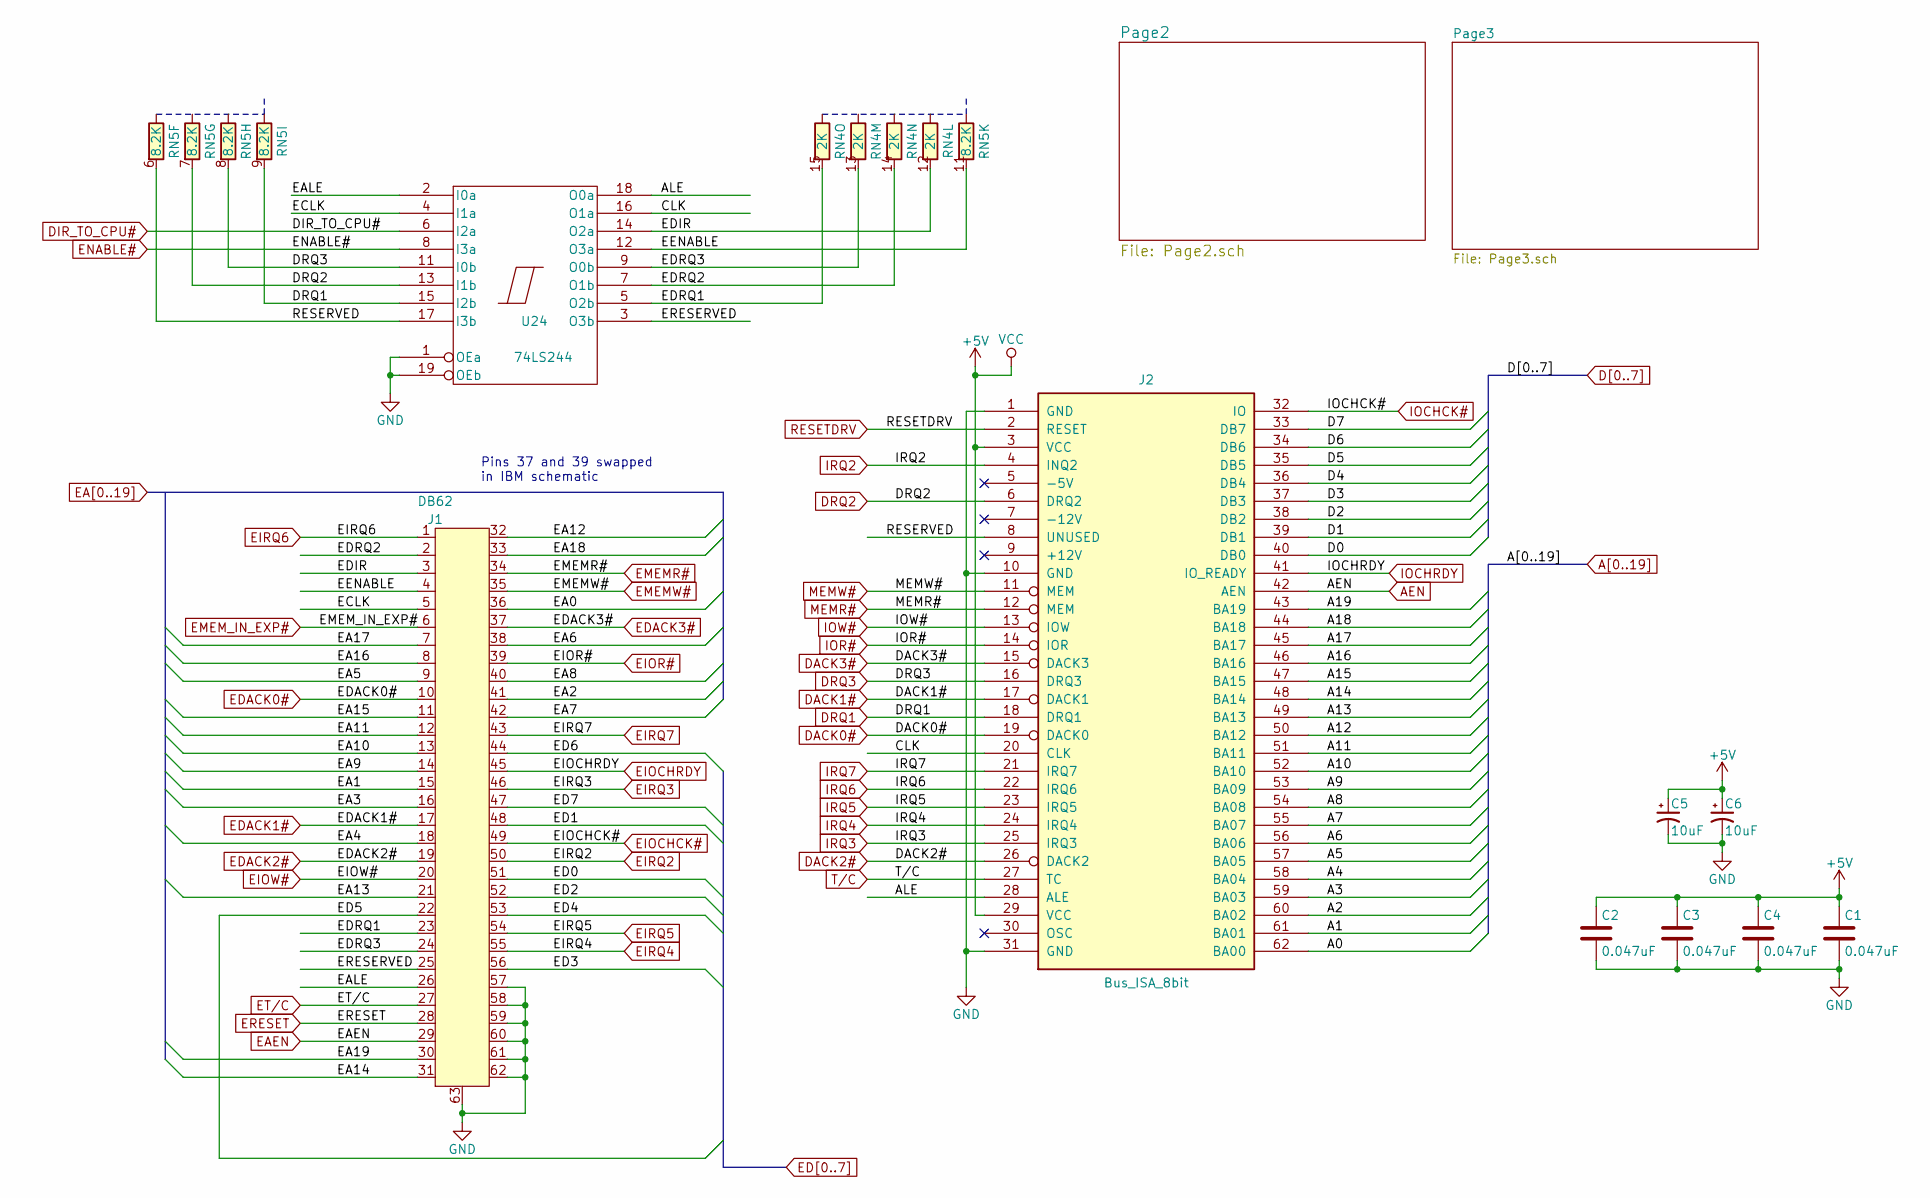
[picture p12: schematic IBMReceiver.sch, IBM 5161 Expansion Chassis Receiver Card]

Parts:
C1, C2, C3, C4: 0.047uF; C_Disc_D0.2in_W0.1in_P0.2in
C5, C6: 10uF; C_Disc_D0.2in_W0.1in_P0.2in
J1: DB62
J2: Bus_ISA_8bit; BUS_PC
RN4: 2K; DIP254P762X635-16
RN5: 8.2K; DIP254P762X635-16
U24: 74LS244; DIP254P762X635-20

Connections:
+5V: C1.1, C2.1, C3.1, C4.1, C5.1, C6.1, J2.3 (VCC), J2.29 (VCC), U24.20 (VCC); also elsewhere on the board
/ALE: J2.28 (ALE), U24.18 (O0a)
/CLK: J2.20 (CLK), U24.16 (O1a)
/EALE: J1.26, U24.2 (I0a)
/ECLK: J1.5, U24.4 (I1a)
/EDIR: J1.3, RN4.12, U24.14 (O2a)
/EDRQ1: J1.23, RN4.15, U24.5 (O2b)
/EDRQ2: J1.2, RN4.14, U24.7 (O1b)
/EDRQ3: J1.24, RN4.13, U24.9 (O0b)
/EENABLE: J1.4, RN5.11, U24.12 (O3a)
/ERESERVED: J1.25, U24.3 (O3b)
/RESERVED: J2.8 (UNUSED), RN5.6, U24.17 (I3b)
A0: J2.62 (BA00); also elsewhere on the board
A1: J2.61 (BA01); also elsewhere on the board
A2: J2.60 (BA02); also elsewhere on the board
A3: J2.59 (BA03); also elsewhere on the board
A4: J2.58 (BA04); also elsewhere on the board
A5: J2.57 (BA05); also elsewhere on the board
A6: J2.56 (BA06); also elsewhere on the board
A7: J2.55 (BA07); also elsewhere on the board
A8: J2.54 (BA08); also elsewhere on the board
A9: J2.53 (BA09); also elsewhere on the board
A10: J2.52 (BA10); also elsewhere on the board
A11: J2.51 (BA11); also elsewhere on the board
A12: J2.50 (BA12); also elsewhere on the board
A13: J2.49 (BA13); also elsewhere on the board
A14: J2.48 (BA14); also elsewhere on the board
A15: J2.47 (BA15); also elsewhere on the board
A16: J2.46 (BA16); also elsewhere on the board
A17: J2.45 (BA17); also elsewhere on the board
A18: J2.44 (BA18); also elsewhere on the board
A19: J2.43 (BA19); also elsewhere on the board
AEN: J2.42 (AEN); also elsewhere on the board
D0: J2.40 (DB0); also elsewhere on the board
D1: J2.39 (DB1); also elsewhere on the board
D2: J2.38 (DB2); also elsewhere on the board
D3: J2.37 (DB3); also elsewhere on the board
D4: J2.36 (DB4); also elsewhere on the board
D5: J2.35 (DB5); also elsewhere on the board
D6: J2.34 (DB6); also elsewhere on the board
D7: J2.33 (DB7); also elsewhere on the board
DACK0#: J2.19 (DACK0); also elsewhere on the board
DACK1#: J2.17 (DACK1); also elsewhere on the board
DACK2#: J2.26 (DACK2); also elsewhere on the board
DACK3#: J2.15 (DACK3); also elsewhere on the board
DIR_TO_CPU#: U24.6 (I2a); also elsewhere on the board
DRQ1: J2.18 (DRQ1), RN5.9, U24.15 (I2b); also elsewhere on the board
DRQ2: J2.6 (DRQ2), RN5.7, U24.13 (I1b); also elsewhere on the board
DRQ3: J2.16 (DRQ3), RN5.8, U24.11 (I0b); also elsewhere on the board
EA0: J1.36; also elsewhere on the board
EA1: J1.15; also elsewhere on the board
EA2: J1.41; also elsewhere on the board
EA3: J1.16; also elsewhere on the board
EA4: J1.18; also elsewhere on the board
EA5: J1.9; also elsewhere on the board
EA6: J1.38; also elsewhere on the board
EA7: J1.42; also elsewhere on the board
EA8: J1.40; also elsewhere on the board
EA9: J1.14; also elsewhere on the board
EA10: J1.13; also elsewhere on the board
EA11: J1.12; also elsewhere on the board
EA12: J1.32; also elsewhere on the board
EA13: J1.21; also elsewhere on the board
EA14: J1.31; also elsewhere on the board
EA15: J1.11; also elsewhere on the board
EA16: J1.8; also elsewhere on the board
EA17: J1.7; also elsewhere on the board
EA18: J1.33; also elsewhere on the board
EA19: J1.30; also elsewhere on the board
EAEN: J1.29; also elsewhere on the board
ED0: J1.51; also elsewhere on the board
ED1: J1.48; also elsewhere on the board
ED2: J1.52; also elsewhere on the board
ED3: J1.56; also elsewhere on the board
ED4: J1.53; also elsewhere on the board
ED5: J1.22; also elsewhere on the board
ED6: J1.44; also elsewhere on the board
ED7: J1.47; also elsewhere on the board
EDACK0#: J1.10; also elsewhere on the board
EDACK1#: J1.17; also elsewhere on the board
EDACK2#: J1.19; also elsewhere on the board
EDACK3#: J1.37; also elsewhere on the board
EIOCHCK#: J1.49; also elsewhere on the board
EIOCHRDY: J1.45; also elsewhere on the board
EIOR#: J1.39; also elsewhere on the board
EIOW#: J1.20; also elsewhere on the board
EIRQ2: J1.50; also elsewhere on the board
EIRQ3: J1.46; also elsewhere on the board
EIRQ4: J1.55; also elsewhere on the board
EIRQ5: J1.54; also elsewhere on the board
EIRQ6: J1.1; also elsewhere on the board
EIRQ7: J1.43; also elsewhere on the board
EMEMR#: J1.34; also elsewhere on the board
EMEMW#: J1.35; also elsewhere on the board
EMEM_IN_EXP#: J1.6; also elsewhere on the board
ENABLE#: U24.8 (I3a); also elsewhere on the board
ERESET: J1.28; also elsewhere on the board
ET/C: J1.27; also elsewhere on the board
GND: C1.2, C2.2, C3.2, C4.2, C5.2, C6.2, J1.57, J1.58, J1.59, J1.60, J1.61, J1.62, J1.63, J2.1 (GND), J2.10 (GND), J2.31 (GND), U24.1 (OEa), U24.10 (GND), U24.19 (OEb); also elsewhere on the board
IOCHCK#: J2.32 (IO); also elsewhere on the board
IOCHRDY: J2.41 (IO_READY); also elsewhere on the board
IOR#: J2.14 (IOR); also elsewhere on the board
IOW#: J2.13 (IOW); also elsewhere on the board
IRQ2: J2.4 (INQ2); also elsewhere on the board
IRQ3: J2.25 (IRQ3); also elsewhere on the board
IRQ4: J2.24 (IRQ4); also elsewhere on the board
IRQ5: J2.23 (IRQ5); also elsewhere on the board
IRQ6: J2.22 (IRQ6); also elsewhere on the board
IRQ7: J2.21 (IRQ7); also elsewhere on the board
MEMR#: J2.12 (MEM); also elsewhere on the board
MEMW#: J2.11 (MEM); also elsewhere on the board
RESETDRV: J2.2 (RESET); also elsewhere on the board
T/C: J2.27 (TC); also elsewhere on the board

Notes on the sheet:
Pins 37 and 39 swapped in IBM schematic

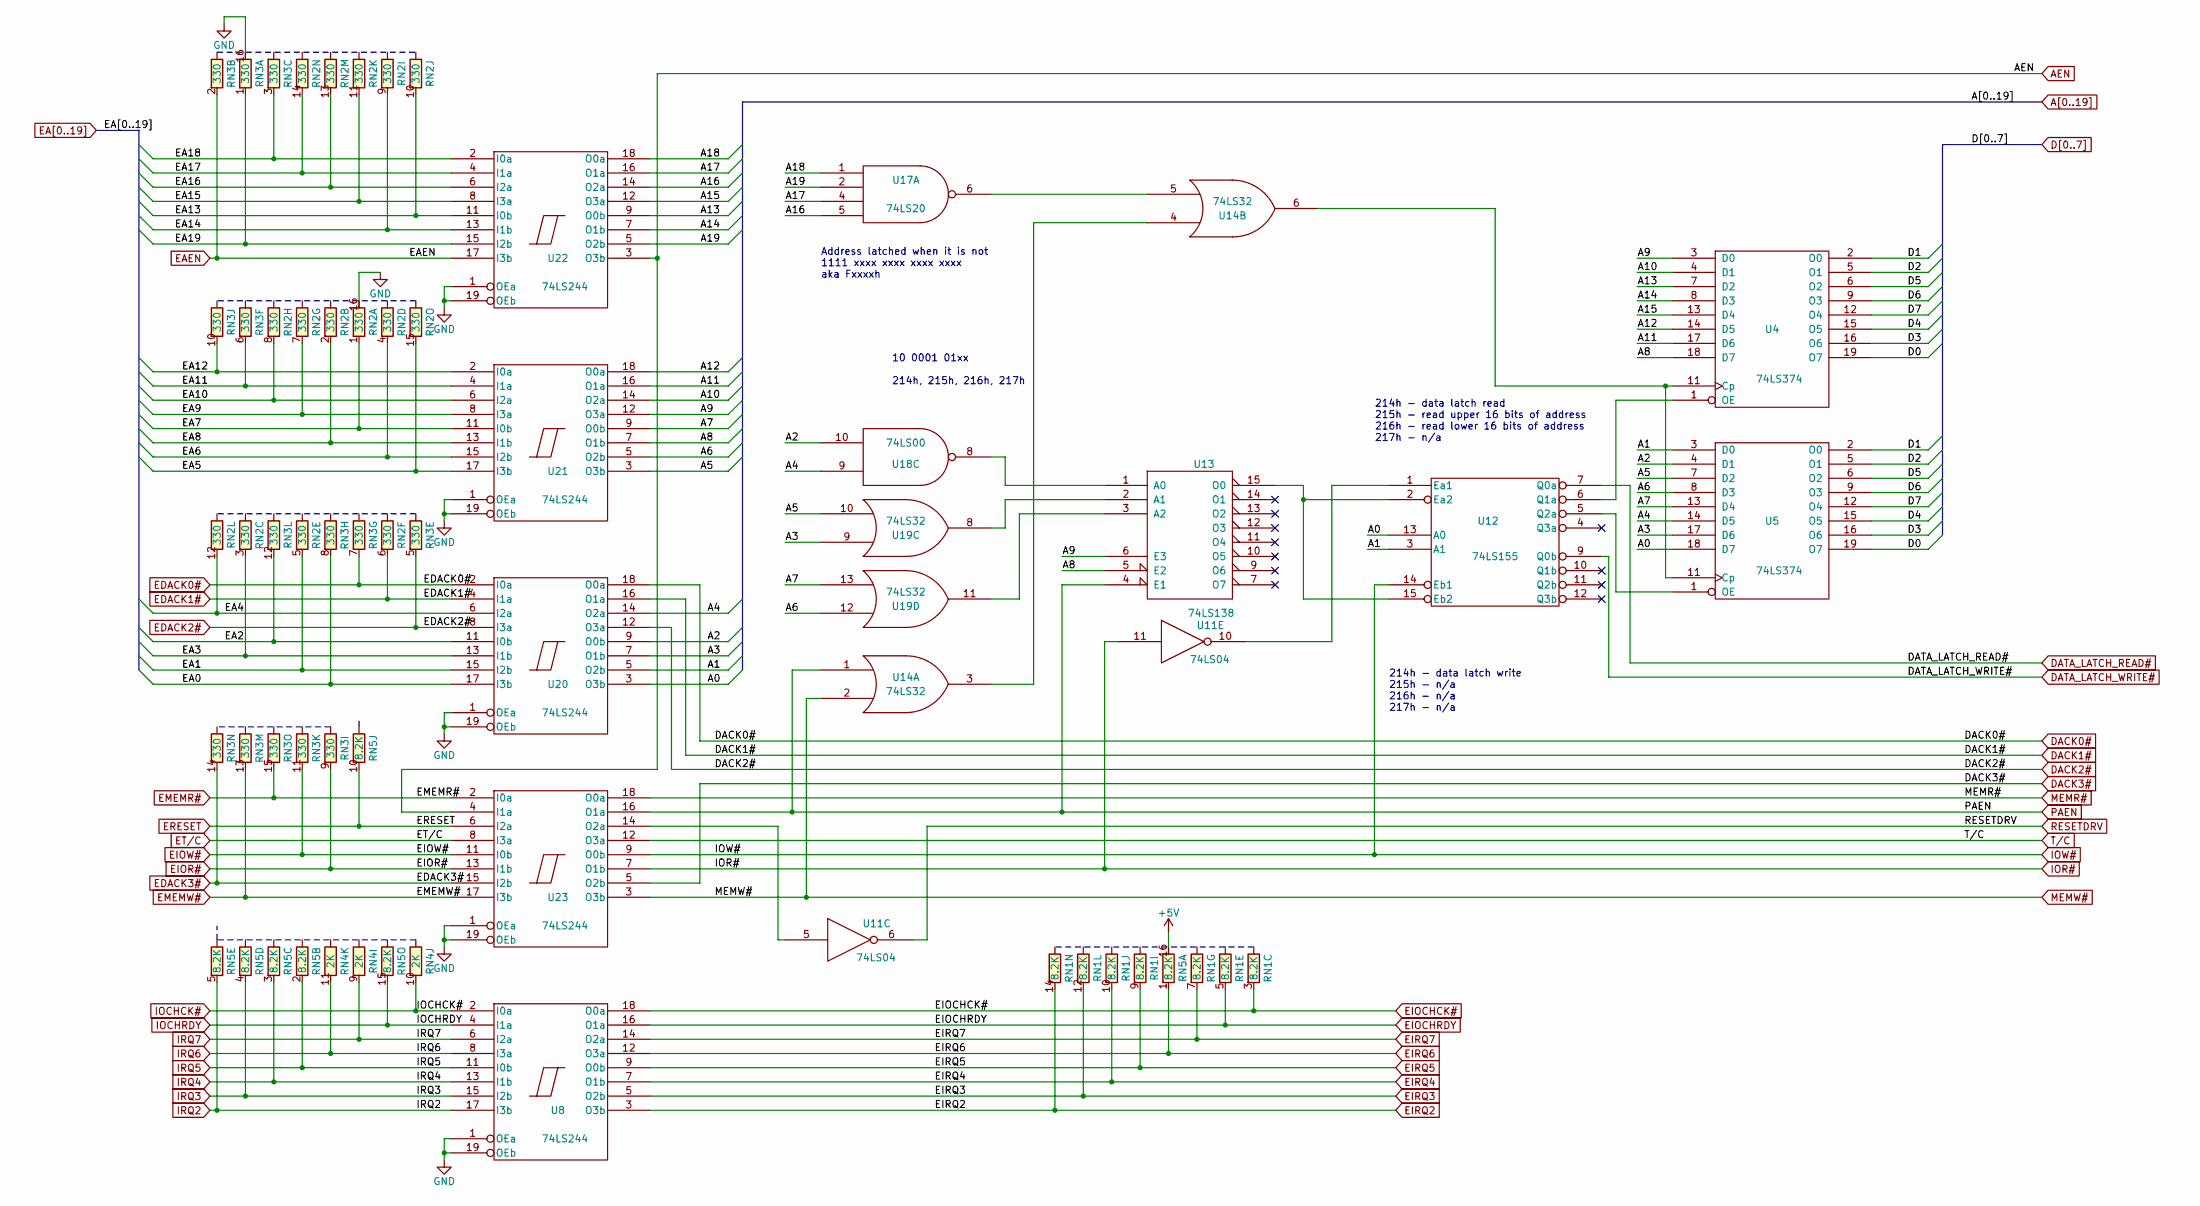
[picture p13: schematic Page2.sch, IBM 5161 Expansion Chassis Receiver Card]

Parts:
RN1, RN5: 8.2K; DIP254P762X635-16
RN2, RN3: 330; DIP254P762X635-16
RN4: 2K; DIP254P762X635-16
U4, U5: 74LS374; DIP254P762X635-20
U8, U20, U21, U22, U23: 74LS244; DIP254P762X635-20
U11: 74LS04; DIP254P762X635-14
U12: 74LS155; DIP254P762X635-16
U13: 74LS138; DIP254P762X635-16
U14, U19: 74LS32; DIP254P762X635-14
U17: 74LS20; DIP254P762X635-14
U18: 74LS00; DIP254P762X635-14

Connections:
+5V: RN5.16, U4.20 (VCC), U5.20 (VCC), U8.20 (VCC), U11.14 (VCC), U12.16 (VCC), U13.16 (VCC), U14.14 (VCC), U17.14 (VCC), U18.14 (VCC), U19.14 (VCC), U20.20 (VCC), U21.20 (VCC), U22.20 (VCC), U23.20 (VCC); also elsewhere on the board
A0: U5.18 (D7), U12.13 (A0), U20.3 (O3b); also elsewhere on the board
A1: U5.3 (D0), U12.3 (A1), U20.5 (O2b); also elsewhere on the board
A2: U5.4 (D1), U18.10, U20.9 (O0b); also elsewhere on the board
A3: U5.17 (D6), U19.9, U20.7 (O1b); also elsewhere on the board
A4: U5.14 (D5), U18.9, U20.14 (O2a); also elsewhere on the board
A5: U5.7 (D2), U19.10, U21.3 (O3b); also elsewhere on the board
A6: U5.8 (D3), U19.12, U21.5 (O2b); also elsewhere on the board
A7: U5.13 (D4), U19.13, U21.9 (O0b); also elsewhere on the board
A8: U4.18 (D7), U13.5 (E2), U21.7 (O1b); also elsewhere on the board
A9: U4.3 (D0), U13.6 (E3), U21.12 (O3a); also elsewhere on the board
A10: U4.4 (D1), U21.14 (O2a); also elsewhere on the board
A11: U4.17 (D6), U21.16 (O1a); also elsewhere on the board
A12: U4.14 (D5), U21.18 (O0a); also elsewhere on the board
A13: U4.7 (D2), U22.9 (O0b); also elsewhere on the board
A14: U4.8 (D3), U22.7 (O1b); also elsewhere on the board
A15: U4.13 (D4), U22.12 (O3a); also elsewhere on the board
A16: U17.5, U22.14 (O2a); also elsewhere on the board
A17: U17.4, U22.16 (O1a); also elsewhere on the board
A18: U17.1, U22.18 (O0a); also elsewhere on the board
A19: U17.2, U22.5 (O2b); also elsewhere on the board
AEN: U22.3 (O3b), U23.4 (I1a); also elsewhere on the board
D0: U4.19 (O7), U5.19 (O7); also elsewhere on the board
D1: U4.2 (O0), U5.2 (O0); also elsewhere on the board
D2: U4.5 (O1), U5.5 (O1); also elsewhere on the board
D3: U4.16 (O6), U5.16 (O6); also elsewhere on the board
D4: U4.15 (O5), U5.15 (O5); also elsewhere on the board
D5: U4.6 (O2), U5.6 (O2); also elsewhere on the board
D6: U4.9 (O3), U5.9 (O3); also elsewhere on the board
D7: U4.12 (O4), U5.12 (O4); also elsewhere on the board
DACK0#: U20.18 (O0a); also elsewhere on the board
DACK1#: U20.16 (O1a); also elsewhere on the board
DACK2#: U20.12 (O3a); also elsewhere on the board
DACK3#: U23.5 (O2b); also elsewhere on the board
DATA_LATCH_READ#: U12.7 (Q0a); also elsewhere on the board
DATA_LATCH_WRITE#: U12.9 (Q0b); also elsewhere on the board
EA0: RN3.8, U20.17 (I3b); also elsewhere on the board
EA1: RN2.5, U20.15 (I2b); also elsewhere on the board
EA2: RN3.12, U20.11 (I0b); also elsewhere on the board
EA3: RN2.3, U20.13 (I1b); also elsewhere on the board
EA4: RN2.12, U20.6 (I2a); also elsewhere on the board
EA5: RN2.15, U21.17 (I3b); also elsewhere on the board
EA6: RN2.4, U21.15 (I2b); also elsewhere on the board
EA7: RN2.1, U21.11 (I0b); also elsewhere on the board
EA8: RN2.2, U21.13 (I1b); also elsewhere on the board
EA9: RN2.7, U21.8 (I3a); also elsewhere on the board
EA10: RN2.8, U21.6 (I2a); also elsewhere on the board
EA11: RN3.6, U21.4 (I1a); also elsewhere on the board
EA12: RN3.10, U21.2 (I0a); also elsewhere on the board
EA13: RN2.10, U22.11 (I0b); also elsewhere on the board
EA14: RN2.9, U22.13 (I1b); also elsewhere on the board
EA15: RN2.11, U22.8 (I3a); also elsewhere on the board
EA16: RN2.13, U22.6 (I2a); also elsewhere on the board
EA17: RN2.14, U22.4 (I1a); also elsewhere on the board
EA18: RN3.3, U22.2 (I0a); also elsewhere on the board
EA19: RN3.1, U22.15 (I2b); also elsewhere on the board
EAEN: RN3.2, U22.17 (I3b); also elsewhere on the board
EDACK0#: RN3.7, U20.2 (I0a); also elsewhere on the board
EDACK1#: RN2.6, U20.4 (I1a); also elsewhere on the board
EDACK2#: RN3.5, U20.8 (I3a); also elsewhere on the board
EDACK3#: RN3.14, U23.15 (I2b); also elsewhere on the board
EIOCHCK#: RN1.3, U8.18 (O0a); also elsewhere on the board
EIOCHRDY: RN1.5, U8.16 (O1a); also elsewhere on the board
EIOR#: RN3.9, U23.13 (I1b); also elsewhere on the board
EIOW#: RN3.11, U23.11 (I0b); also elsewhere on the board
EIRQ2: RN1.14, U8.3 (O3b); also elsewhere on the board
EIRQ3: RN1.12, U8.5 (O2b); also elsewhere on the board
EIRQ4: RN1.10, U8.7 (O1b); also elsewhere on the board
EIRQ5: RN1.9, U8.9 (O0b); also elsewhere on the board
EIRQ6: RN5.1, U8.12 (O3a); also elsewhere on the board
EIRQ7: RN1.7, U8.14 (O2a); also elsewhere on the board
EMEMR#: RN3.15, U23.2 (I0a); also elsewhere on the board
EMEMW#: RN3.13, U23.17 (I3b); also elsewhere on the board
ERESET: RN5.10, U23.6 (I2a); also elsewhere on the board
ET/C: U23.8 (I3a); also elsewhere on the board
GND: RN2.16, RN3.16, U4.10 (GND), U5.10 (GND), U8.1 (OEa), U8.10 (GND), U8.19 (OEb), U11.7 (GND), U12.8 (GND), U13.8 (GND), U14.7 (GND), U17.7 (GND), U18.7 (GND), U19.7 (GND), U20.1 (OEa), U20.10 (GND), U20.19 (OEb), U21.1 (OEa), U21.10 (GND), U21.19 (OEb), U22.1 (OEa), U22.10 (GND), U22.19 (OEb), U23.1 (OEa), U23.10 (GND), U23.19 (OEb); also elsewhere on the board
IOCHCK#: RN4.10, U8.2 (I0a); also elsewhere on the board
IOCHRDY: RN5.15, U8.4 (I1a); also elsewhere on the board
IOR#: U11.11, U23.7 (O1b); also elsewhere on the board
IOW#: U12.14 (Eb1), U23.9 (O0b); also elsewhere on the board
IRQ2: RN5.5, U8.17 (I3b); also elsewhere on the board
IRQ3: RN5.4, U8.15 (I2b); also elsewhere on the board
IRQ4: RN5.3, U8.13 (I1b); also elsewhere on the board
IRQ5: RN5.2, U8.11 (I0b); also elsewhere on the board
IRQ6: RN4.11, U8.8 (I3a); also elsewhere on the board
IRQ7: RN4.9, U8.6 (I2a); also elsewhere on the board
MEMR#: U23.18 (O0a); also elsewhere on the board
MEMW#: U14.2, U23.3 (O3b); also elsewhere on the board
unnamed: U11.5, U23.14 (O2a)
unnamed: U11.10, U12.1 (Ea1)
unnamed: U5.1 (OE), U12.5 (Q2a)
unnamed: U4.1 (OE), U12.6 (Q1a)
unnamed: U12.2 (Ea2), U12.15 (Eb2), U13.15 (O0)
unnamed: U13.1 (A0), U18.8
unnamed: U13.2 (A1), U19.8
unnamed: U13.3 (A2), U19.11
unnamed: U14.3, U14.4
unnamed: U14.5, U17.6
unnamed: U4.11 (Cp), U5.11 (Cp), U14.6
PAEN: U13.4 (E1), U14.1, U23.16 (O1a); also elsewhere on the board
RESETDRV: U11.6; also elsewhere on the board
T/C: U23.12 (O3a); also elsewhere on the board

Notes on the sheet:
10 0001 01xx 214h, 215h, 216h, 217h
Address latched when it is not 1111 xxxx xxxx xxxx xxxx aka Fxxxxh
214h - data latch read 215h - read upper 16 bits of address 216h - read lower 16 bits of address 217h - n/a
214h - data latch write 215h - n/a 216h - n/a 217h - n/a

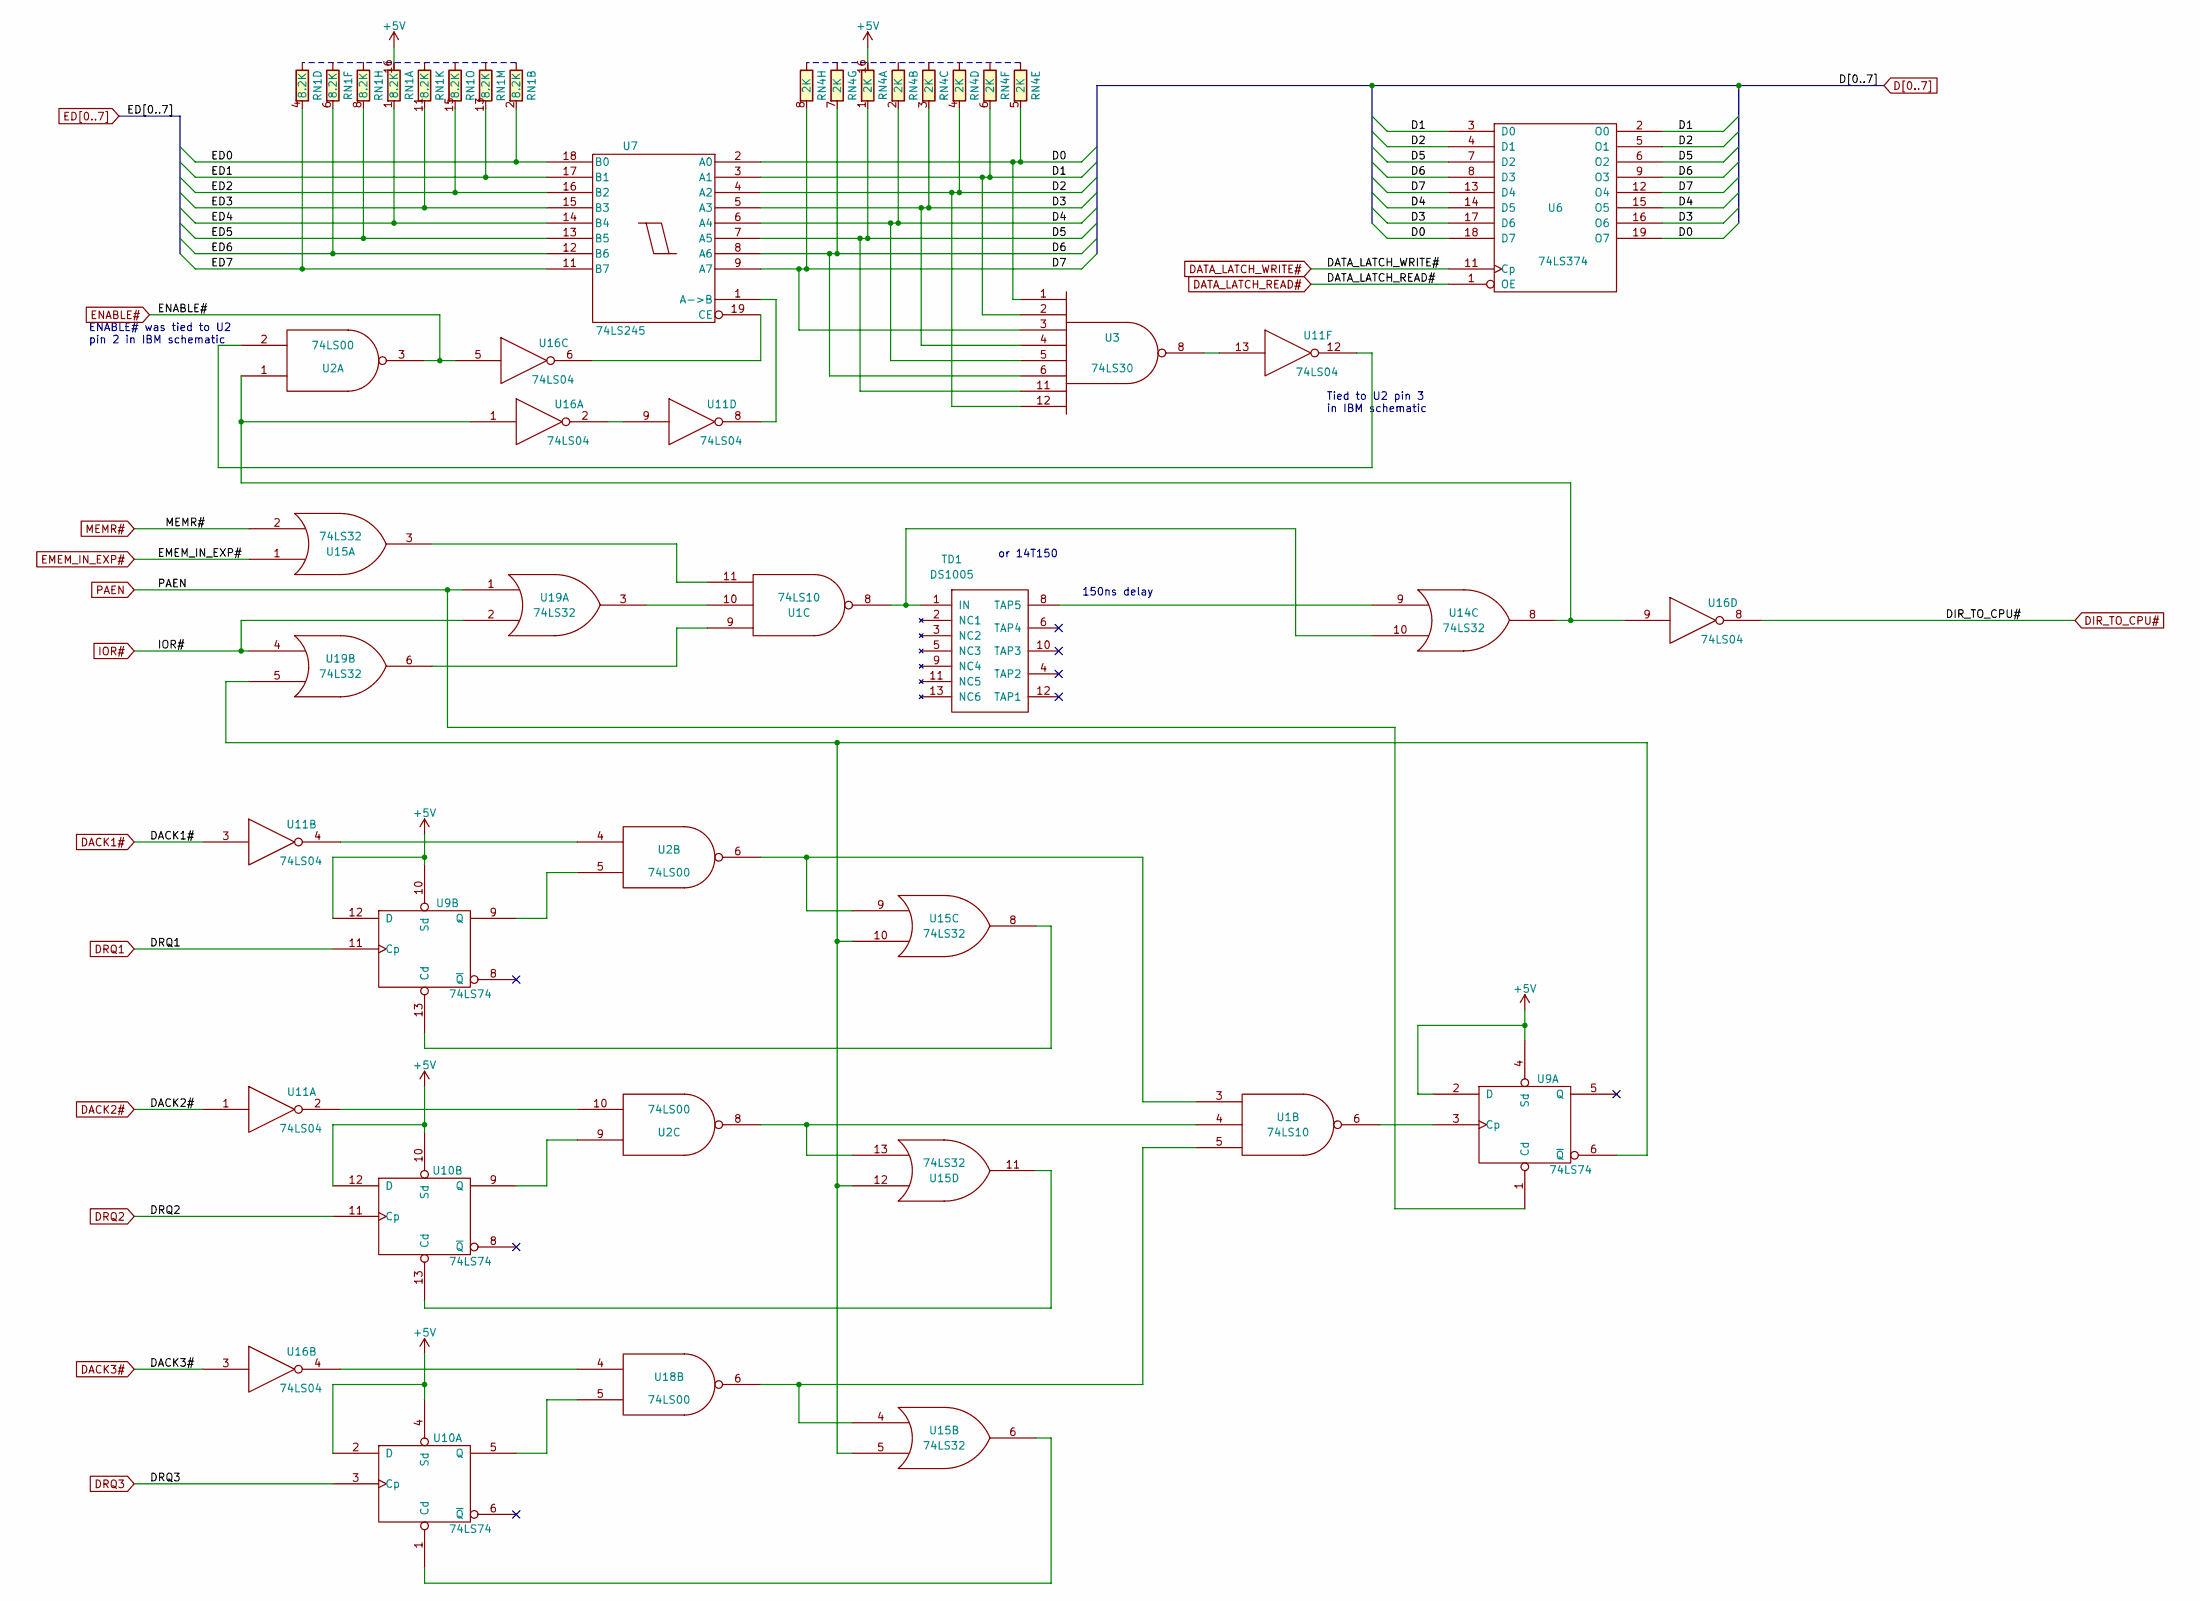
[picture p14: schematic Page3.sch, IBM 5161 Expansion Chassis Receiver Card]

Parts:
RN1: 8.2K; DIP254P762X635-16
RN4: 2K; DIP254P762X635-16
TD1: DS1005; DIP254P762X635-14
U1: 74LS10; DIP254P762X635-14
U2, U18: 74LS00; DIP254P762X635-14
U3: 74LS30; DIP254P762X635-14
U6: 74LS374; DIP254P762X635-20
U7: 74LS245; DIP254P762X635-20
U9, U10: 74LS74; DIP254P762X635-14
U11, U16: 74LS04; DIP254P762X635-14
U14, U15, U19: 74LS32; DIP254P762X635-14

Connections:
+5V: RN1.16, RN4.16, TD1.14 (VCC), U1.14 (VCC), U2.14 (VCC), U3.14 (VCC), U6.20 (VCC), U7.20 (VCC), U9.2 (D), U9.4 (Sd), U9.10 (Sd), U9.12 (D), U9.14 (VCC), U10.2 (D), U10.4 (Sd), U10.10 (Sd), U10.12 (D), U10.14 (VCC), U11.14 (VCC), U14.14 (VCC), U15.14 (VCC), U16.14 (VCC), U18.14 (VCC), U19.14 (VCC); also elsewhere on the board
D0: RN4.5, U3.1, U6.18 (D7), U6.19 (O7), U7.2 (A0); also elsewhere on the board
D1: RN4.6, U3.2, U6.2 (O0), U6.3 (D0), U7.3 (A1); also elsewhere on the board
D2: RN4.4, U3.12, U6.4 (D1), U6.5 (O1), U7.4 (A2); also elsewhere on the board
D3: RN4.3, U3.4, U6.16 (O6), U6.17 (D6), U7.5 (A3); also elsewhere on the board
D4: RN4.2, U3.5, U6.14 (D5), U6.15 (O5), U7.6 (A4); also elsewhere on the board
D5: RN4.1, U3.11, U6.6 (O2), U6.7 (D2), U7.7 (A5); also elsewhere on the board
D6: RN4.7, U3.6, U6.8 (D3), U6.9 (O3), U7.8 (A6); also elsewhere on the board
D7: RN4.8, U3.3, U6.12 (O4), U6.13 (D4), U7.9 (A7); also elsewhere on the board
DACK1#: U11.3; also elsewhere on the board
DACK2#: U11.1; also elsewhere on the board
DACK3#: U16.3; also elsewhere on the board
DATA_LATCH_READ#: U6.1 (OE); also elsewhere on the board
DATA_LATCH_WRITE#: U6.11 (Cp); also elsewhere on the board
DIR_TO_CPU#: U16.8; also elsewhere on the board
DRQ1: U9.11 (Cp); also elsewhere on the board
DRQ2: U10.11 (Cp); also elsewhere on the board
DRQ3: U10.3 (Cp); also elsewhere on the board
ED0: RN1.2, U7.18 (B0); also elsewhere on the board
ED1: RN1.13, U7.17 (B1); also elsewhere on the board
ED2: RN1.15, U7.16 (B2); also elsewhere on the board
ED3: RN1.11, U7.15 (B3); also elsewhere on the board
ED4: RN1.1, U7.14 (B4); also elsewhere on the board
ED5: RN1.8, U7.13 (B5); also elsewhere on the board
ED6: RN1.6, U7.12 (B6); also elsewhere on the board
ED7: RN1.4, U7.11 (B7); also elsewhere on the board
EMEM_IN_EXP#: U15.1; also elsewhere on the board
ENABLE#: U2.3, U16.5; also elsewhere on the board
GND: TD1.7 (GND), U1.7 (GND), U2.7 (GND), U3.7 (GND), U6.10 (GND), U7.10 (GND), U9.7 (GND), U10.7 (GND), U11.7 (GND), U14.7 (GND), U15.7 (GND), U16.7 (GND), U18.7 (GND), U19.7 (GND); also elsewhere on the board
IOR#: U19.2, U19.4; also elsewhere on the board
MEMR#: U15.2; also elsewhere on the board
unnamed: TD1.1 (IN), U1.8, U14.10
unnamed: TD1.8 (TAP5), U14.9
unnamed: U1.3, U2.6, U15.9
unnamed: U1.4, U2.8, U15.13
unnamed: U1.5, U15.4, U18.6
unnamed: U1.6, U9.3 (Cp)
unnamed: U1.9, U19.6
unnamed: U1.10, U19.3
unnamed: U1.11, U15.3
unnamed: U2.5, U9.9 (Q)
unnamed: U10.1 (Cd), U15.6
unnamed: U10.5 (Q), U18.5
unnamed: U2.9, U10.9 (Q)
unnamed: U10.13 (Cd), U15.11
unnamed: U2.10, U11.2
unnamed: U2.4, U11.4
unnamed: U7.1 (A->B), U11.8
unnamed: U11.9, U16.2
unnamed: U2.2, U11.12
unnamed: U3.8, U11.13
unnamed: U2.1, U14.8, U16.1, U16.9
unnamed: U9.13 (Cd), U15.8
unnamed: U9.6 (~Q), U15.5, U15.10, U15.12, U19.5
unnamed: U16.4, U18.4
unnamed: U7.19 (CE), U16.6
PAEN: U9.1 (Cd), U19.1; also elsewhere on the board

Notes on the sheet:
or 14T150
150ns delay
ENABLE# was tied to U2 pin 2 in IBM schematic
Tied to U2 pin 3 in IBM schematic

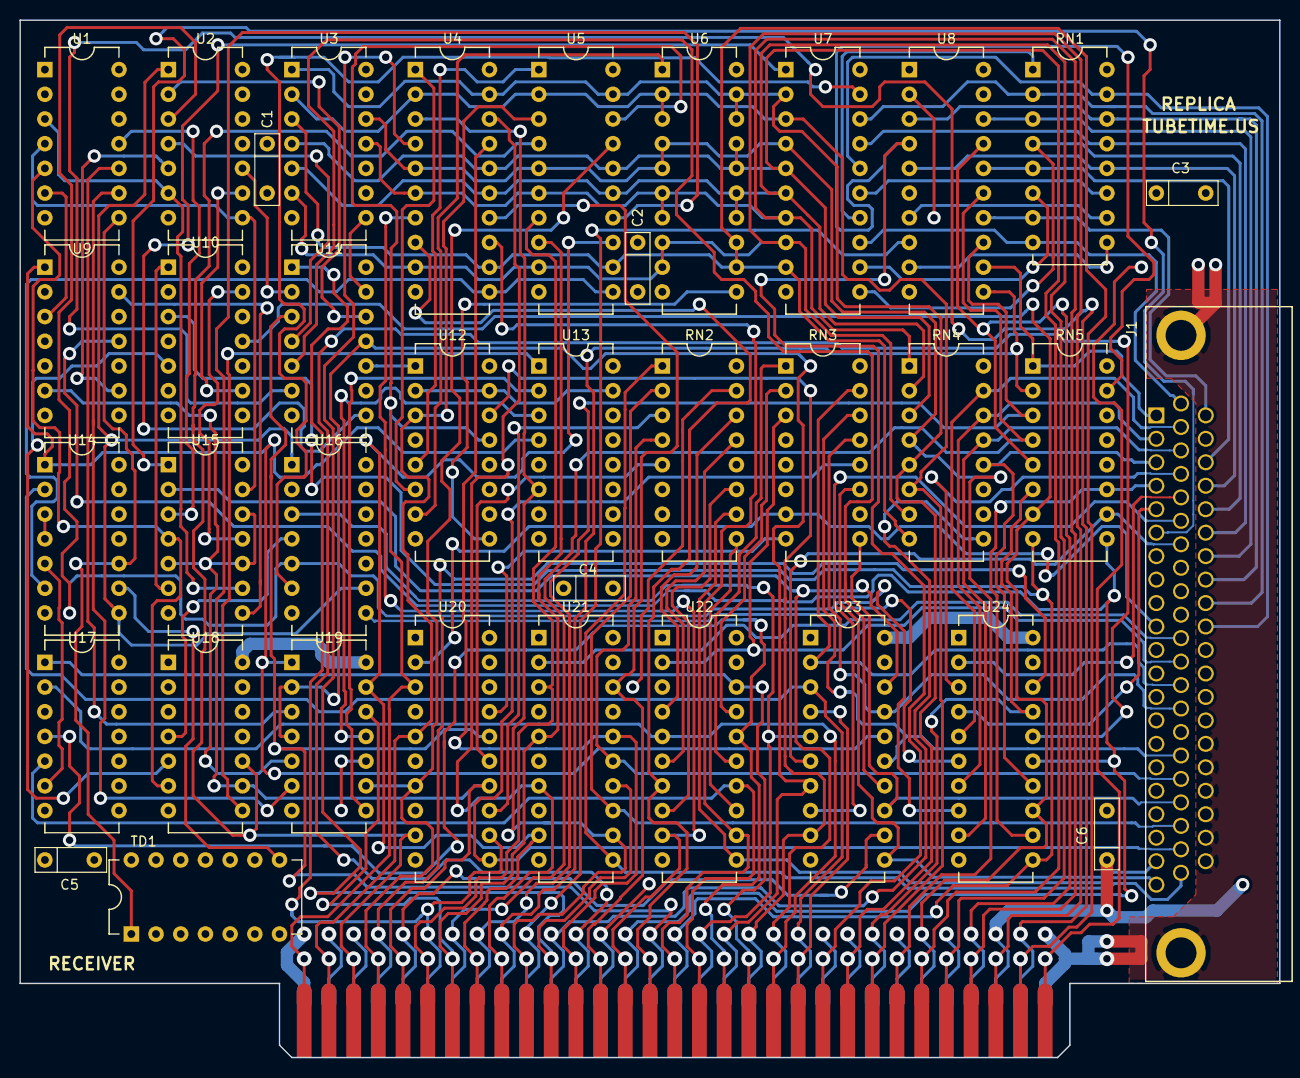
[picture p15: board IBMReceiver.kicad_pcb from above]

Board: 4 copper layers, 129.5 x 106.7 mm, 38 parts (0 on the bottom side), 152 nets.

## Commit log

2018-09-05 Initial project files
    [IBMExtender.kicad_pcb, IBMExtender.sch, IBMExtenderBOM.csv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]
2021-06-26 Add card bracket info

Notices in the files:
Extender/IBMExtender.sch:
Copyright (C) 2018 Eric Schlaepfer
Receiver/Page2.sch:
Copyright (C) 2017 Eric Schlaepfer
